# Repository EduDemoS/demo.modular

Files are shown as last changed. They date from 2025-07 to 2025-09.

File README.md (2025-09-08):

# EduDemoS Modular Weather Station

The EduDemoS Modular Weather Station consists of a central Control Box that can be connected to three other demonstrators (solar, wind and water). Due to its modular nature you can even design and connect your own modules or send measurement data wirelessly to the Internet.

This repository contains all necessary files and is structured as follows:

- [doc](doc) contains documentation such as
  - assembly manual
  - bill of material
- [code](code) contains program code to run the model
- [model](model) contains the printable 3D model

# Licensing

Please note: different licenses apply depending on the type of content.

All documents and 3d models (files ending with .pdf and .stl) are licensed under [CC-BY-NC-SA 4.0](https://creativecommons.org/licenses/by-nc-sa/4.0/).

All files containing code are licensed under [GNU GPL V3](https://www.gnu.org/licenses/gpl-3.0.txt).

# Disclaimer:

Funded by the European Union. Views and opinions expressed are however those of the author(s) only and do not necessarily reflect those of the European Union or the European Education and Culture Executive Agency (EACEA). Neither the European Union nor EACEA can be held responsible for them.

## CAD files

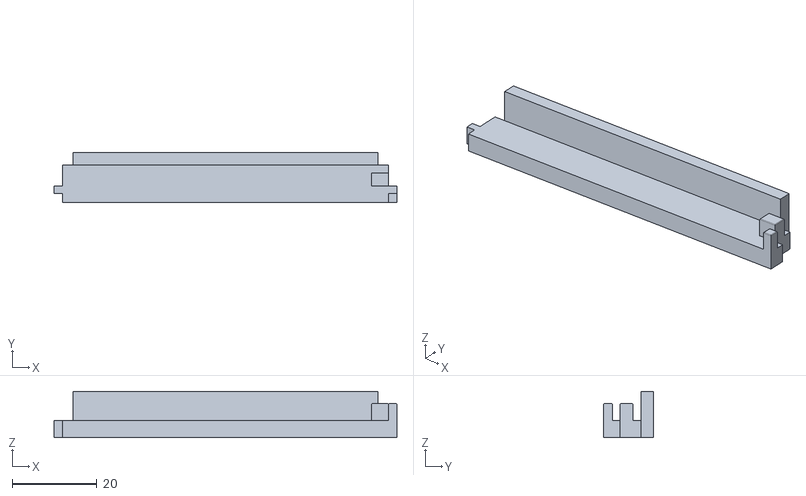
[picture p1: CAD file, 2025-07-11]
model/Controlbox/LCD_Frame_B__Controlbox.stl
80.8 x 11.8 x 10.9

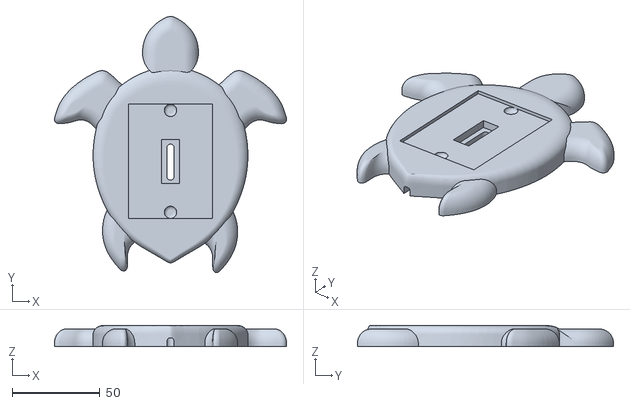
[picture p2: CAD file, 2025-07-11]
model/Sun-Module/Turtle__Sun_Module.stl
132.1 x 145.7 x 12.0

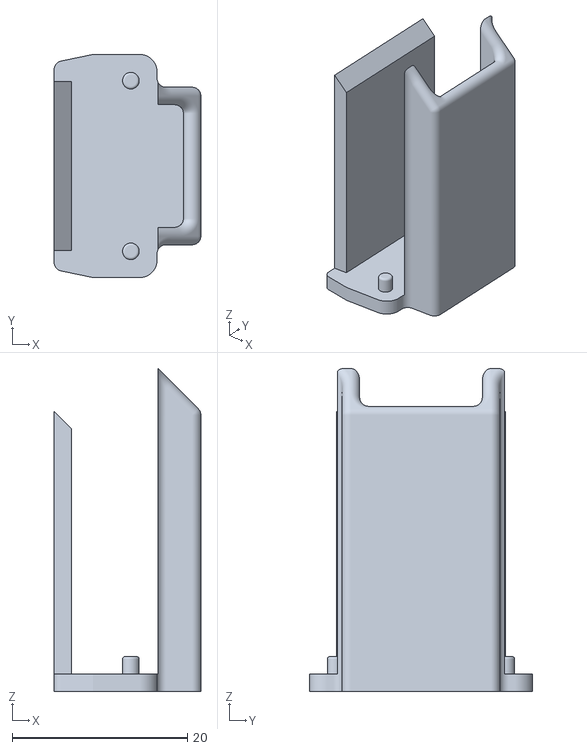
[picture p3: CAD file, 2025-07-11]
model/Water-Module/Electronic_Lid__Water_Module.stl
16.8 x 25.5 x 36.9

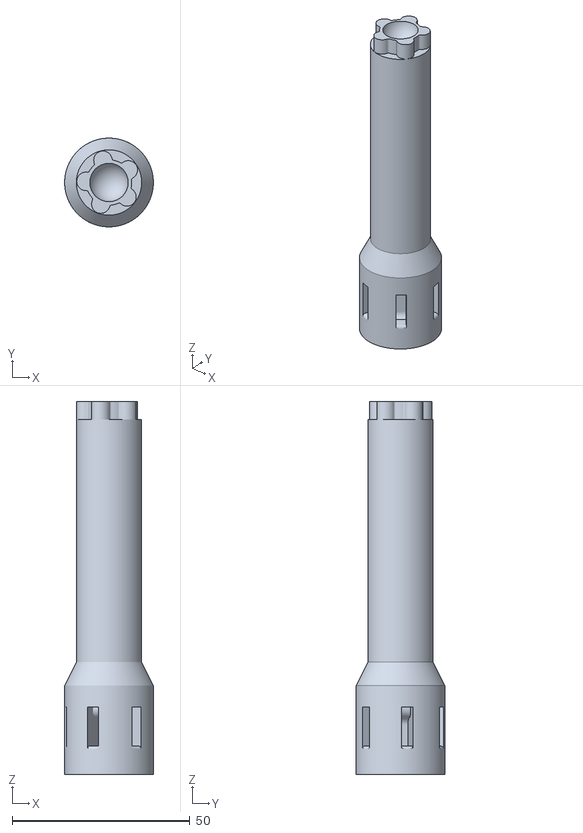
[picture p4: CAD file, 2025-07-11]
model/Wind-Module/Connector__Wind_Module.stl
25.0 x 25.0 x 105.0

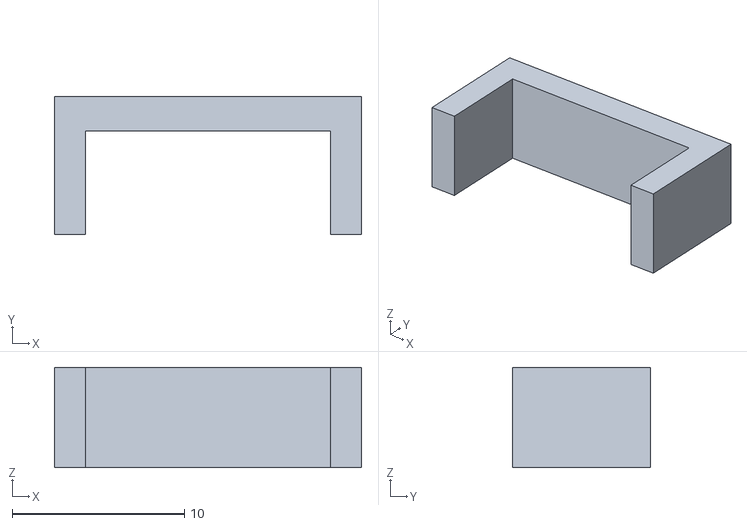
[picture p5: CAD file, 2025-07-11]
model/Controlbox/ACS_Holder__Controlbox.stl
17.8 x 8.00 x 5.80

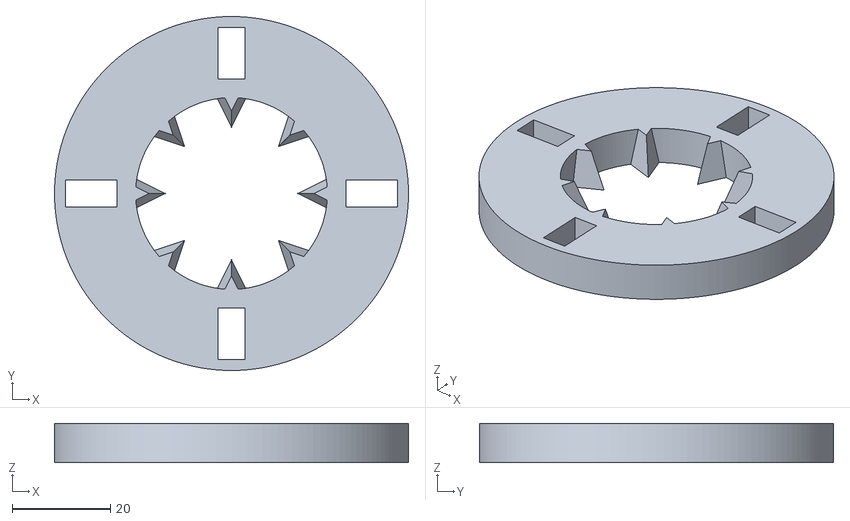
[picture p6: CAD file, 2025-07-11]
model/Water-Module/Lower_Ring__Water_Module.stl
72.0 x 72.0 x 8.00

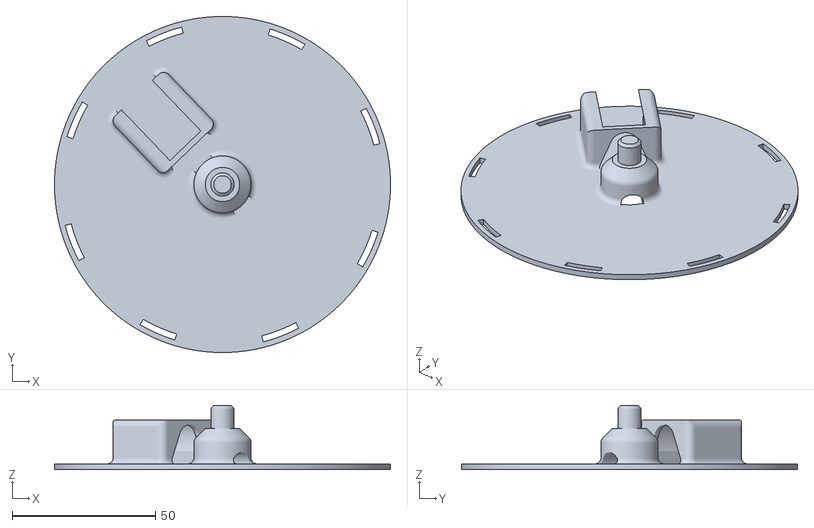
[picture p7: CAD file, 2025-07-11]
model/Wind-Module/Base__Wind_Module.stl
117.5 x 117.5 x 22.4

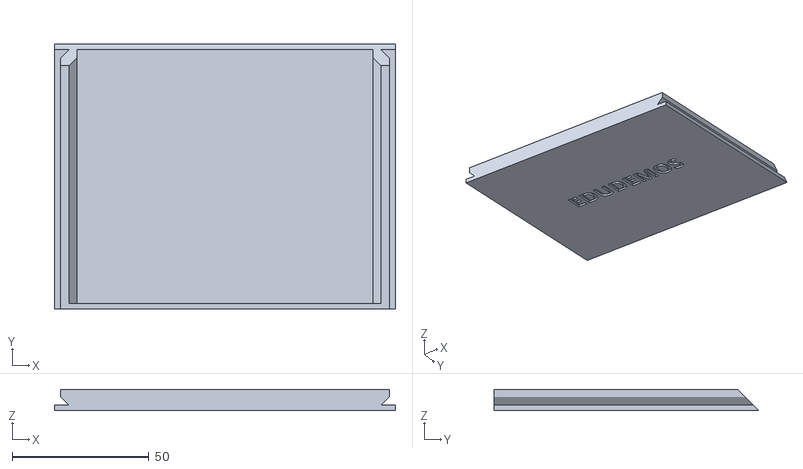
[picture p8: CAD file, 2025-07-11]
model/Controlbox/Lid__Controlbox.stl
124.6 x 96.8 x 7.80

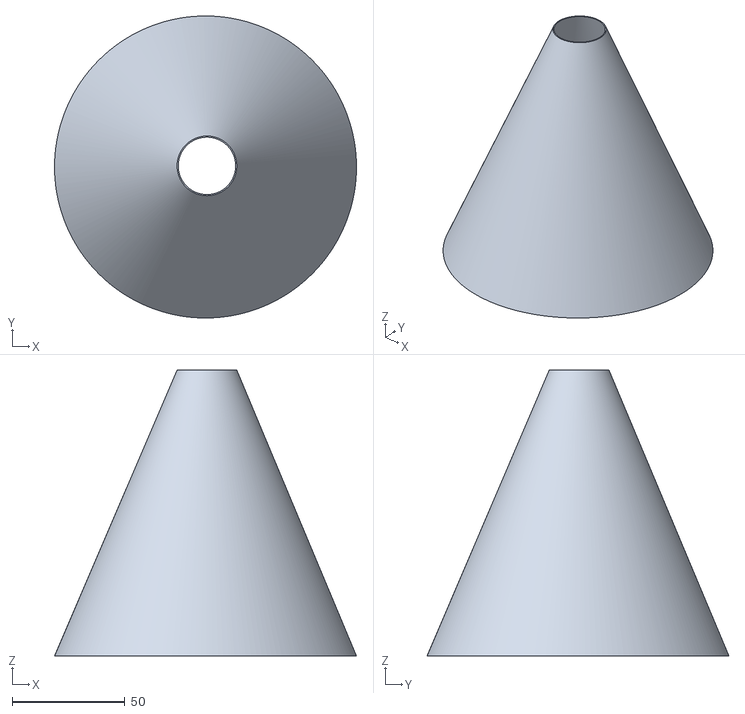
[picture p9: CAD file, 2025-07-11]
model/Water-Module/Collector_Cone__Water_Module.stl
134.1 x 134.1 x 127.0

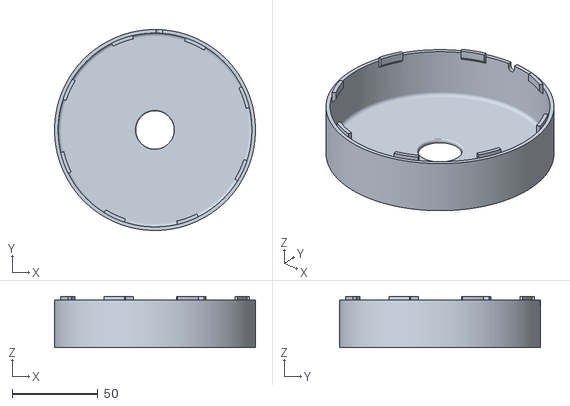
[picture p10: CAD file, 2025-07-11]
model/Wind-Module/Lid__Wind_Module.stl
117.5 x 117.5 x 30.0

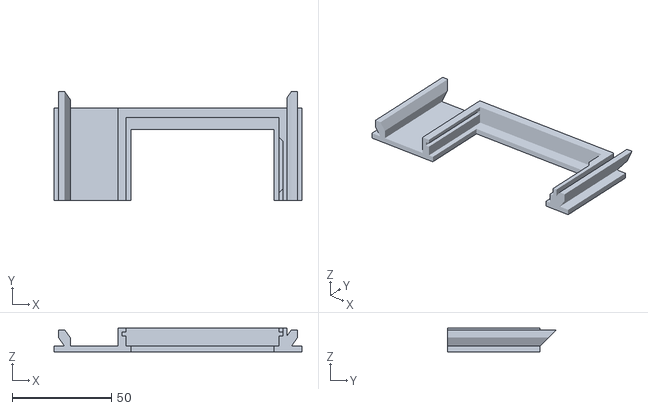
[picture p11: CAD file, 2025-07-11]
model/Controlbox/LCD_Frame_A__Controlbox.stl
124.7 x 54.7 x 11.8

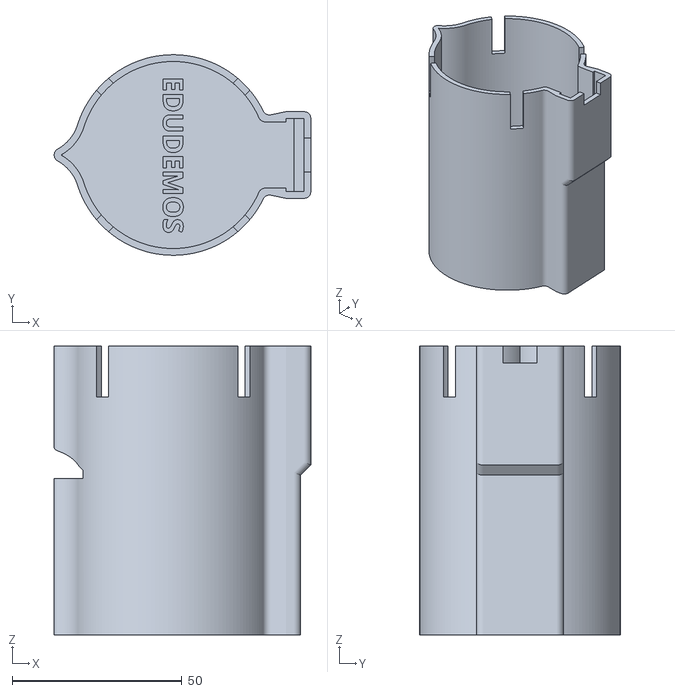
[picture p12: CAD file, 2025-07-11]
model/Water-Module/Cup__Water_Module.stl
75.5 x 59.0 x 85.0

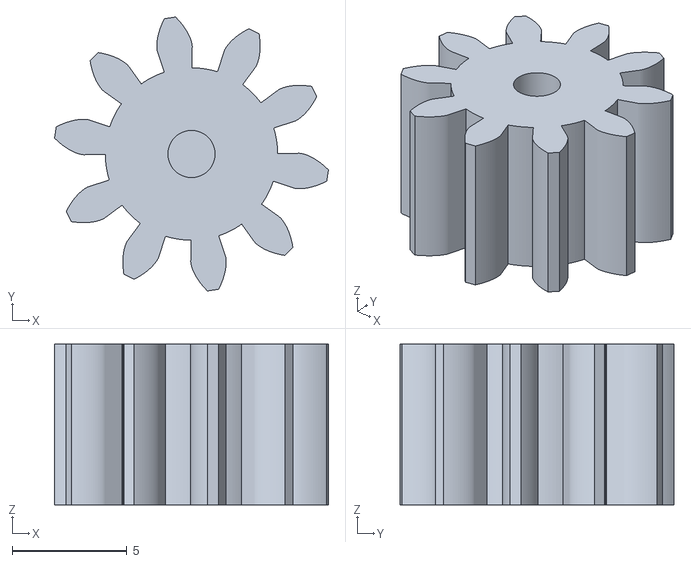
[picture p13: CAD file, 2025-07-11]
model/Wind-Module/Gear_A__Wind_Module.stl
11.9 x 11.9 x 7.00

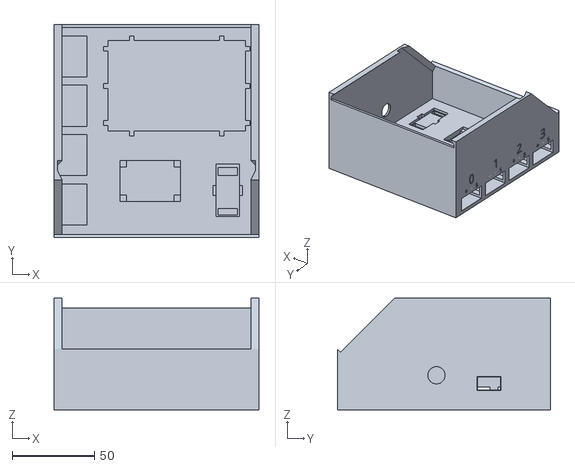
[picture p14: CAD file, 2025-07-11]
model/Controlbox/Base__Controlbox.stl
124.6 x 129.6 x 67.9

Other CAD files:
model/Water-Module/Upper_Ring__Water_Module.stl
model/Water-Module/x4_Cactus__Water_Module.stl

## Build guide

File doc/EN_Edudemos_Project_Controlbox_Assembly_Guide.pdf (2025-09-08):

## EDUcating through Sustainable DEMOnstrators

Funded by the European Union. Views and opinions expressed are however those of the author(s) only and do not necessarily reflect those of the European Union or the European Education and Culture Executive Agency (EACEA). Neither the European Union nor EACEA can be held responsible for them.

## Assembly Guide

# Modular Weather Station

# Controlbox Module

V-09.25

## 1.Materials 2.Step by Step Instructions a.Printing the Parts b.Wiring- and Assemby Instructions 3.Building the Modules 4.Programming 5.Troubleshooting 6.Appendix a.Components with Example Link b.Pinout c.Changing Modules d.Licensing & Disclaimer 7.Contact Information

# Content

# Materials

## Electrical Components

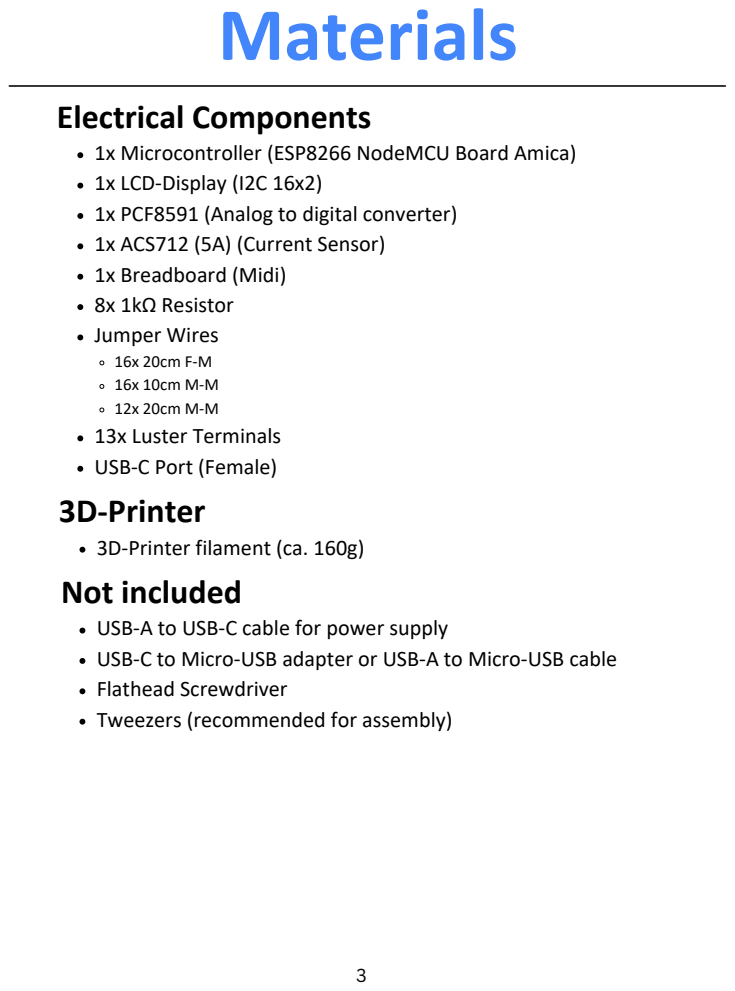
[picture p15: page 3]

1x Microcontroller (ESP8266 NodeMCU Board Amica)
1x LCD-Display (I2C 16x2)
1x PCF8591 (Analog to digital converter)
1x ACS712 (5A) (Current Sensor)
1x Breadboard (Midi)
8x 1kΩ Resistor
Jumper Wires
13x Luster Terminals
USB-C Port (Female)
3D-Printer
3D-Printer filament (ca. 160g)
Not included
USB-A to USB-C cable for power supply
USB-C to Micro-USB adapter or USB-A to Micro-USB cable
Flathead Screwdriver
Tweezers (recommended for assembly)

ESP8266 NodeMCU Board
x1

ACS712
x1

Luster Terminals
x14

x1

x1

Jumper Wire female-to-male (F-M)**
x15

Jumper Wire male-to-male
(M-M)**
x28

USB-C Port Female
x1
Resistor 1kOhm

# Modular Controlbox

### Total 62 elements

## Electronics

*Make sure to remove all jumpers from the PCF8591 **The colours of the jumper wires are irrelevant.

These 6 pins
should not be
connected

# Modular Controlbox

### Total 5 elements

## 3D Printed Parts

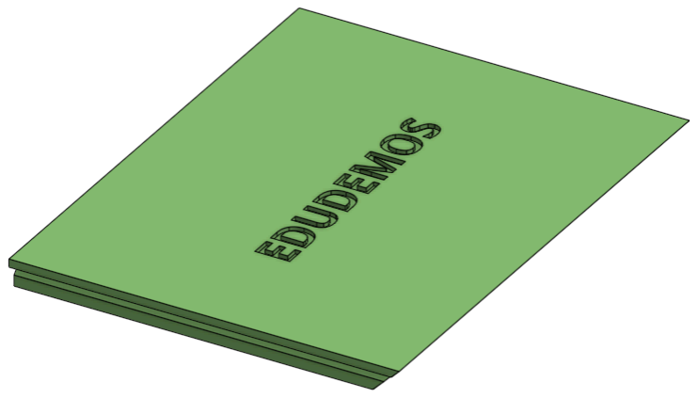
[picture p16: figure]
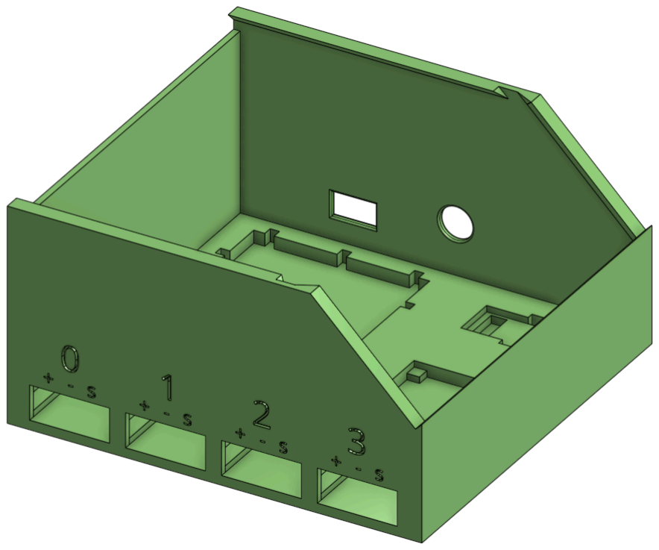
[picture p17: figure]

Controlbox Base
x1

ACS712 Fastener
x1

Controlbox Lid
x1

Display Fastener
x1

Display Holder
x1

This part should be
printed sideways

The STL print files are available on the EduDemoS website:
edudemos.eu/en/demonstrators/

# Step By step Instructions

## a. Print the parts of the Modular Controlbox on any 3D-Printer

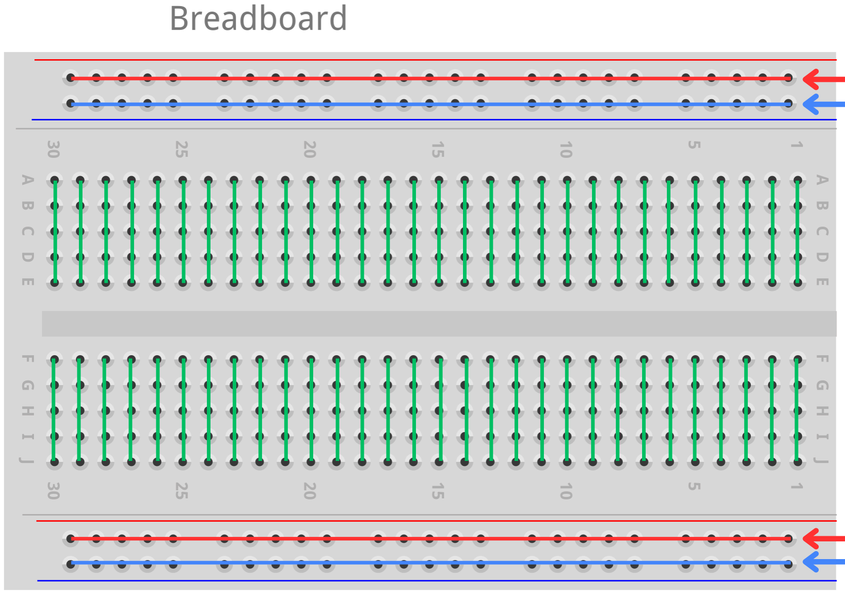
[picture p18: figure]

red-rail

(no internal connection
between the two rails)

blue-rail

## B. Wiring and assembling Instructions

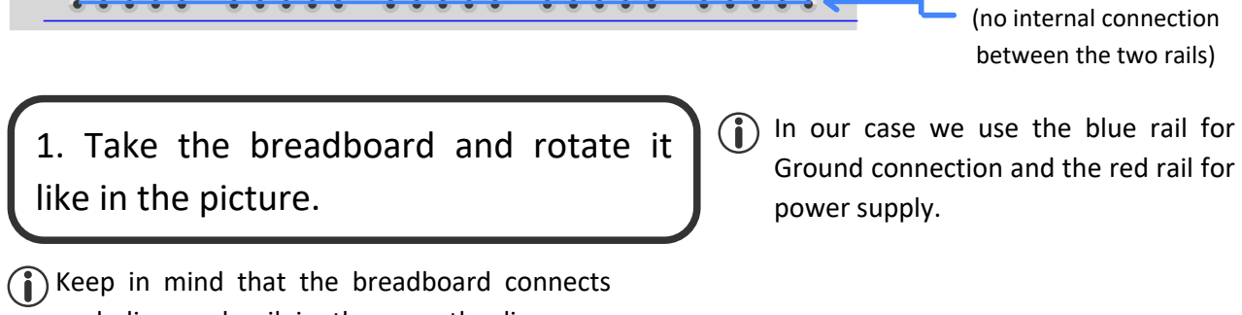
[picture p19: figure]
(no internal connection between the two rails); 1. Take the breadboard and rotate it like in the picture.; In our case we use the blue rail for Ground connection and the red rail for power supply.
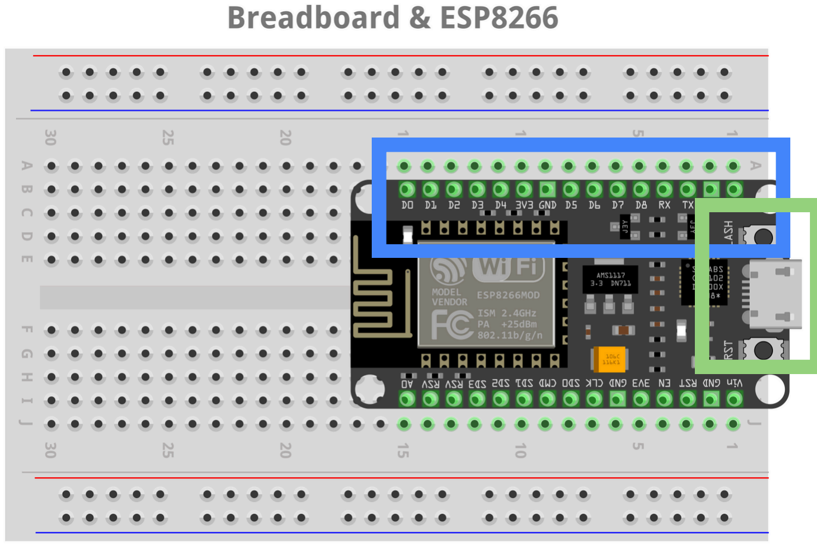
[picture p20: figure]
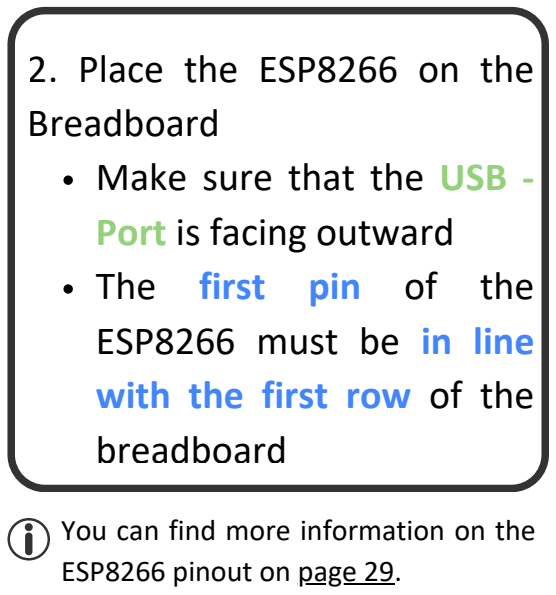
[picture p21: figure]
2. Place the ESP8266 on the Breadboard Make sure that the USB - Port is facing outward The first pin of the ESP8266 must be in line with the first row of the breadboard; You can find more information on the ESP8266 pinout on page 29.

Keep in mind that the breadboard connects each line and rail in the way the lines are drawn. For example a pin or Jumper plugged in to A5 is connected with all Jumper and pins plugged into B5, C5, D5 and E5.

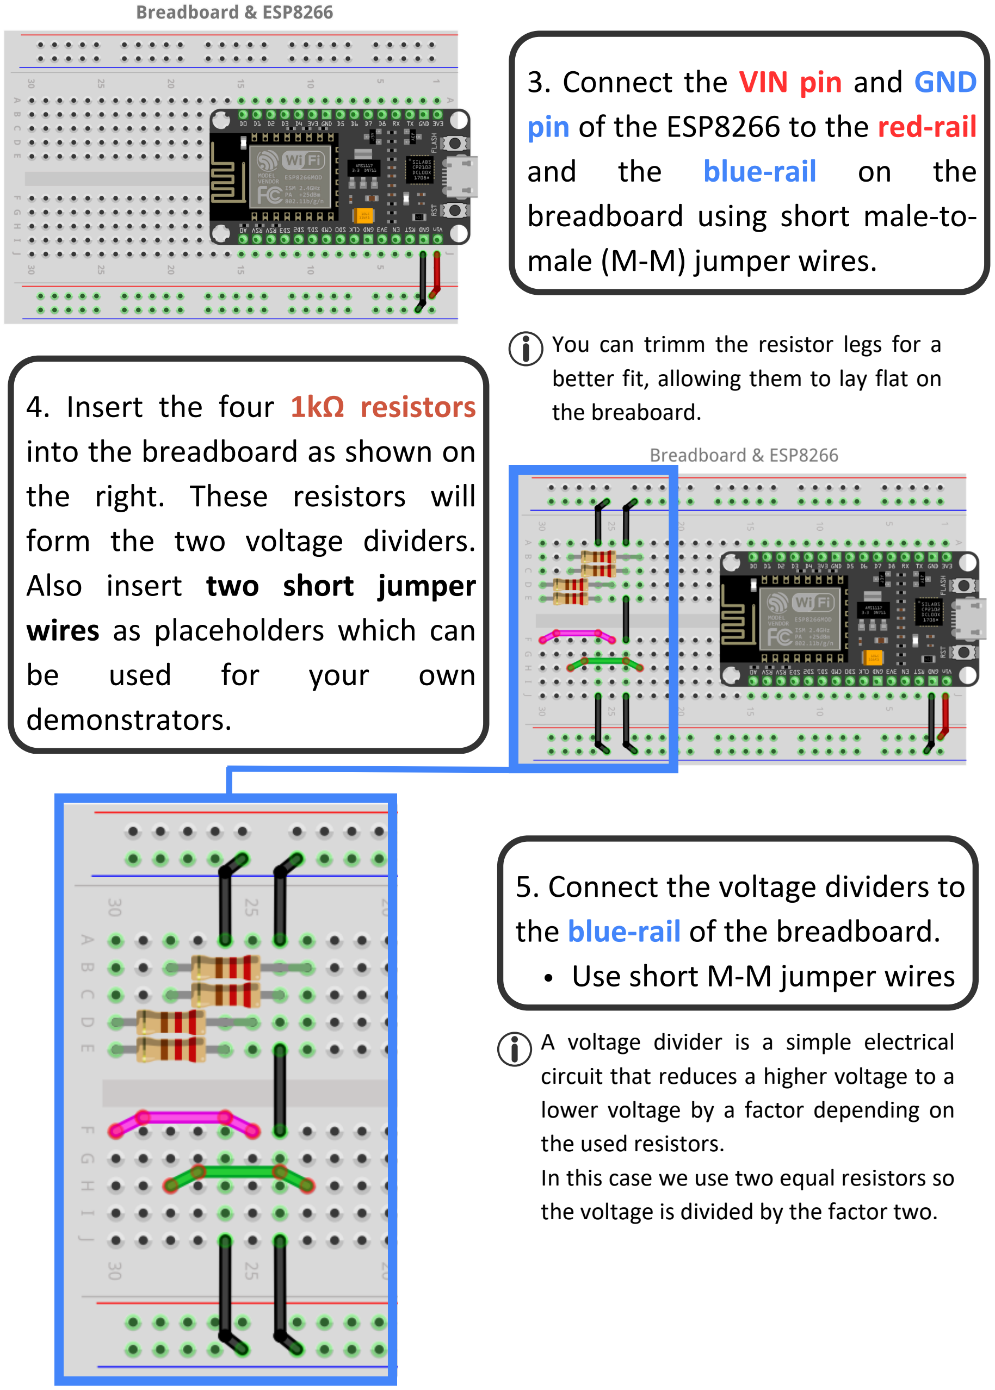
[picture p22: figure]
3. Connect the VIN pin and GND pin of the ESP8266 to the red-rail; and; the; blue-rail; breadboard using short male-to- male (M-M) jumper wires.; 4. Insert the four 1kΩ resistors into the breadboard as shown on the right. These resistors will form the two voltage dividers. Also insert two short jumper wires as placeholders which can; used; for; your; own; demonstrators.; 5. Connect the voltage dividers to the blue-rail of the breadboard. Use short M-M jumper wires; lower voltage by a factor depending on the used resistors.; You can trimm the resistor legs for a; the breaboard.

A voltage divider is a simple electrical circuit that reduces a higher voltage to a

In this case we use two equal resistors so the voltage is divided by the factor two.

better fit, allowing them to lay flat on

I²C is a way for electrical components to communicate. It uses two wires to send and receive digital messages. You can connect multiple components with the same pins because each device has a special adress assigned to it.

6. Connect the D1 and D2 pins from the ESP8266 to rows 18 and 19 on the breadboard.

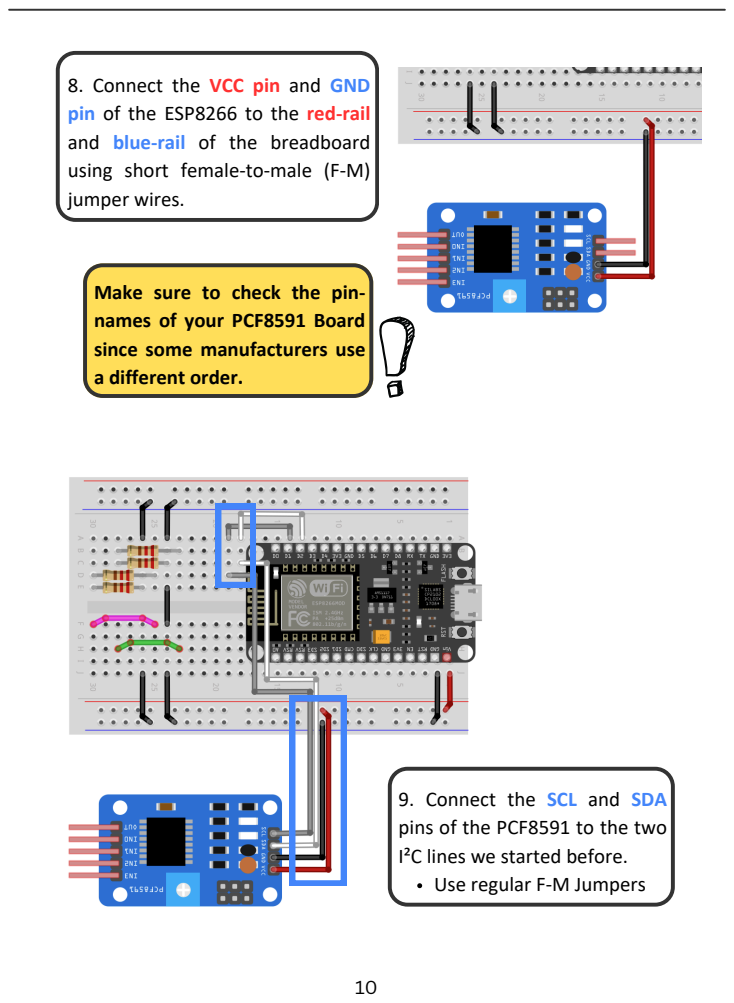
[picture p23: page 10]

8. Connect the VCC pin and GND
pin of the ESP8266 to the red-rail
and blue-rail of the breadboard
using short female-to-male (F-M)
jumper wires.

Make sure to check the pin-
names of your PCF8591 Board
since some manufacturers use
a different order.

9. Connect the SCL and SDA
pins of the PCF8591 to the two
I²C lines we started before.
Use regular F-M Jumpers

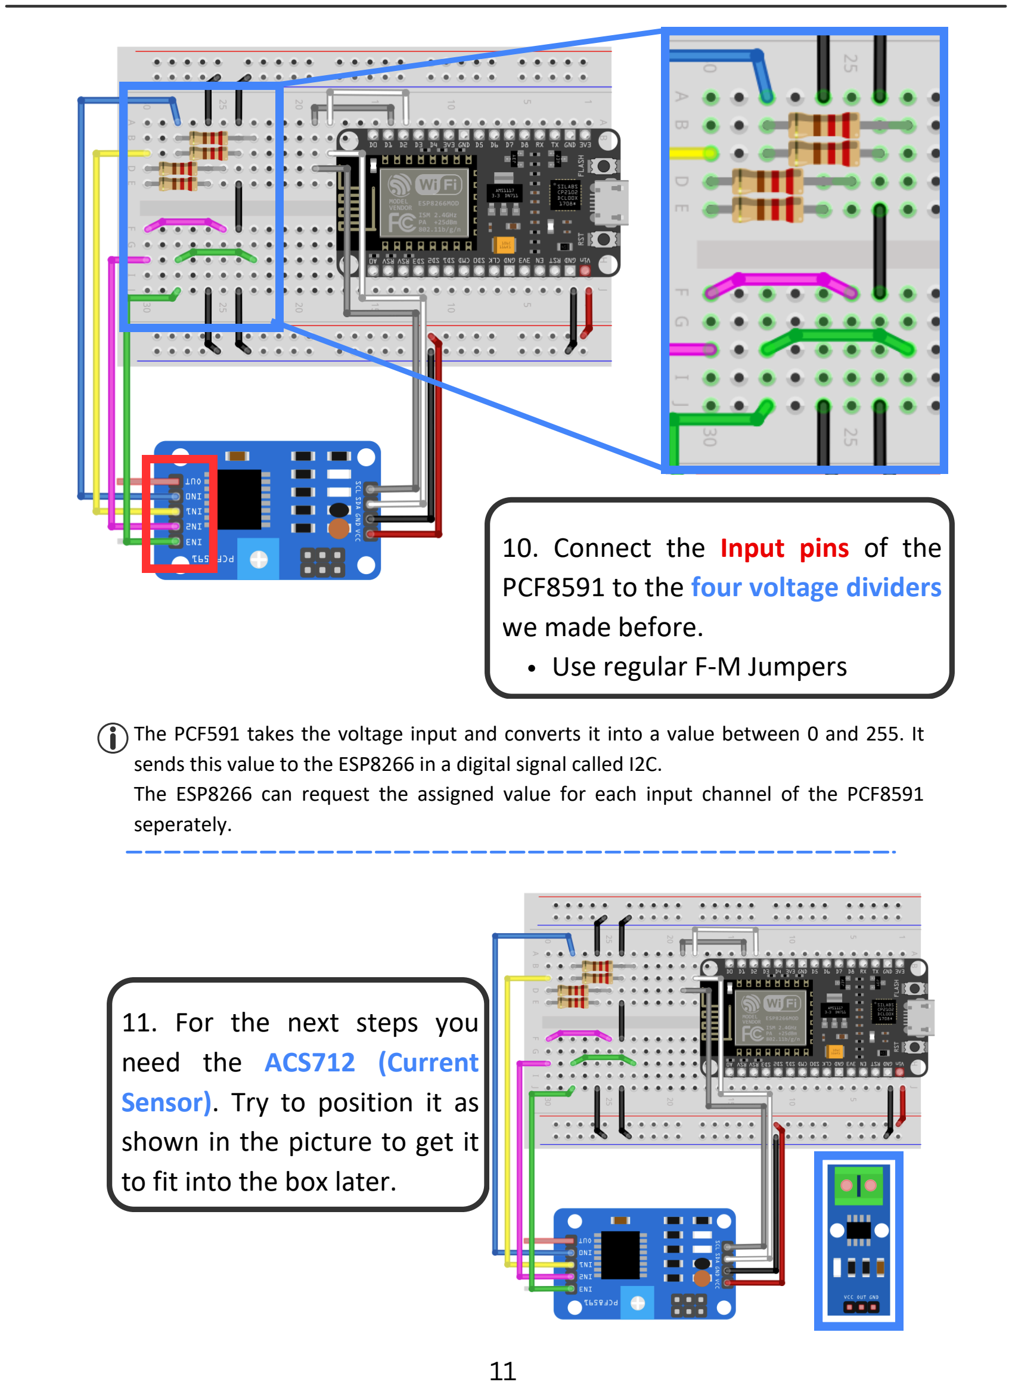
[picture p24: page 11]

11. For the next steps you need the ACS712 (Current
Sensor). Try to position it as shown in the picture to get it to fit into the box later.
10. Connect the Input pins of the PCF8591 to the four voltage dividers we made before.
Use regular F-M Jumpers

The PCF591 takes the voltage input and converts it into a value between 0 and 255. It sends this value to the ESP8266 in a digital signal called I2C.
The ESP8266 can request the assigned value for each input channel of the PCF8591 seperately.

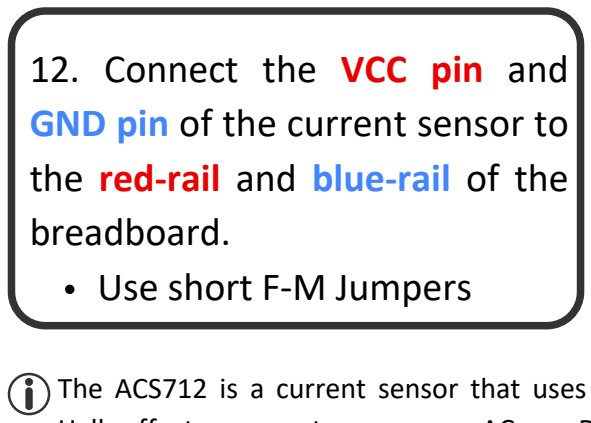
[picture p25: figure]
12. Connect the VCC pin and GND pin of the current sensor to the red-rail and blue-rail of the breadboard. Use short F-M Jumpers

The ACS712 is a current sensor that uses a Hall effect sensor to measure AC or DC current and outputs an analog voltage proportional to the current flow.

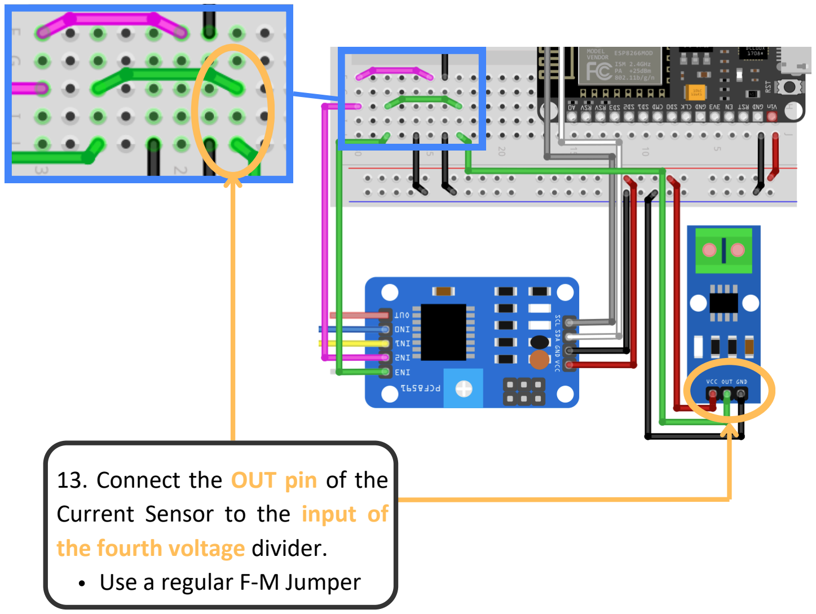
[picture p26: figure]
13. Connect the OUT pin of the Current Sensor to the input of the fourth voltage divider. Use a regular F-M Jumper

15. Get a single Luster
Terminal | so | you | can
connect | the | | USB-C
connector later.
14. Partially unscrew the left terminal connector of the Current Sensor, put one side of the jumper in the opening and screw it tight again. Connect the other end of the jumper wire to the red-rail of the breadboard.
Use a short M-M Jumper

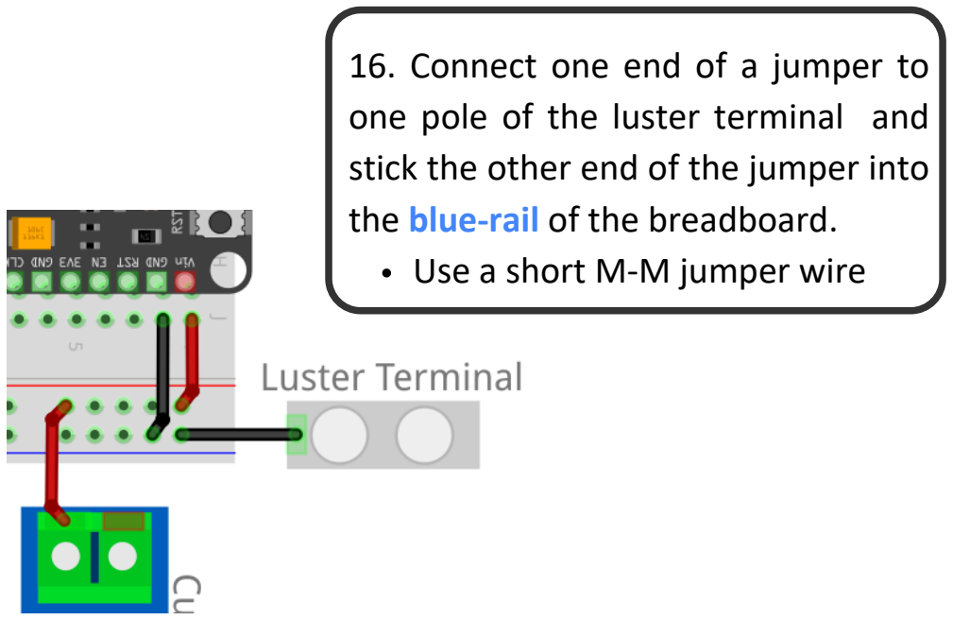
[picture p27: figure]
16. Connect one end of a jumper to one pole of the luster terminal and stick the other end of the jumper into the blue-rail of the breadboard. Use a short M-M jumper wire

17. For the next steps, you will need four luster terminals, each with 3 poles. These terminals will connect the control box to various modules. Position them as shown in the picture to ensure everything fits into the box later.

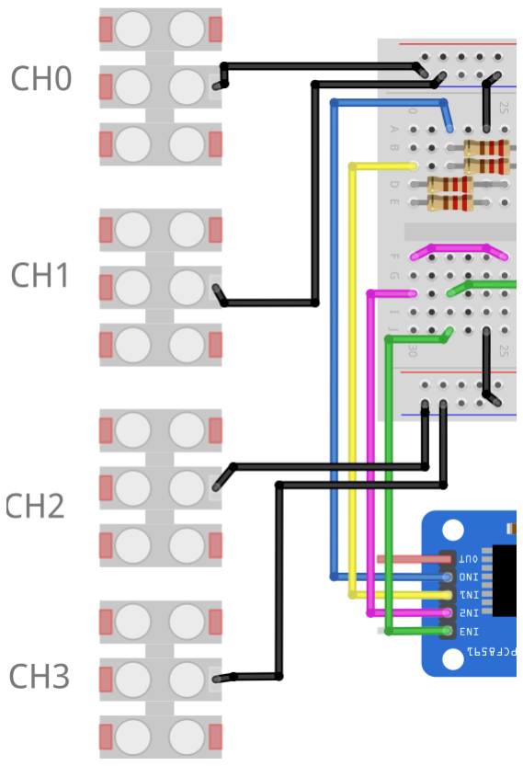
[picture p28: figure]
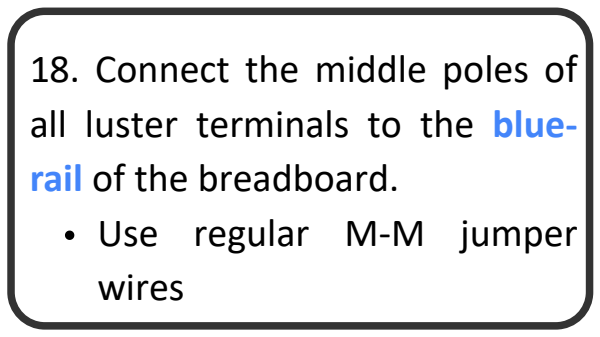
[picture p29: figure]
18. Connect the middle poles of all luster terminals to the blue- rail of the breadboard. Use regular M-M jumper wires

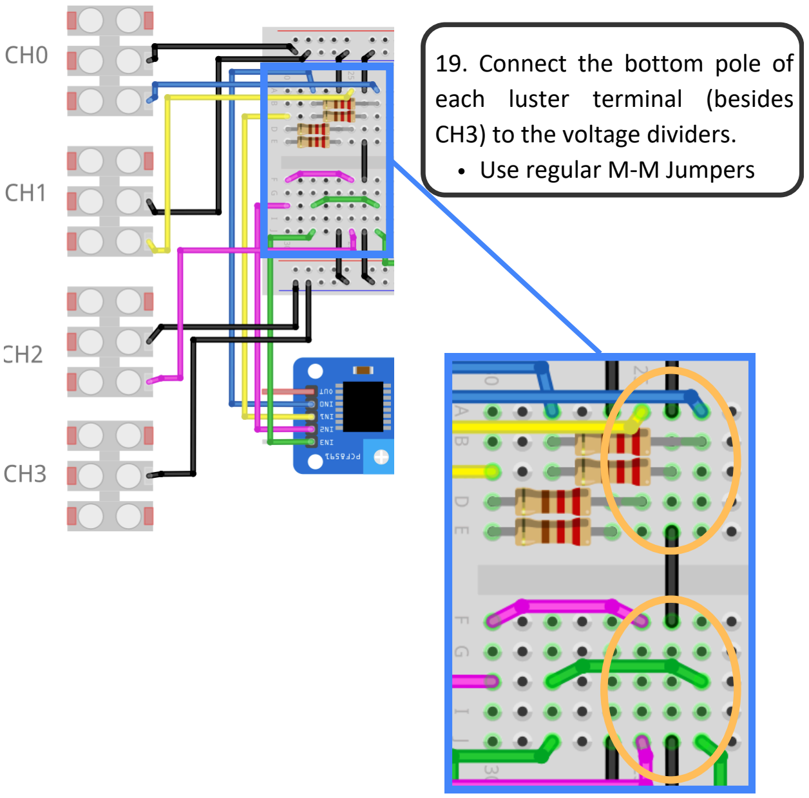
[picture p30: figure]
19. Connect the bottom pole of each luster terminal (besides CH3) to the voltage dividers. Use regular M-M Jumpers
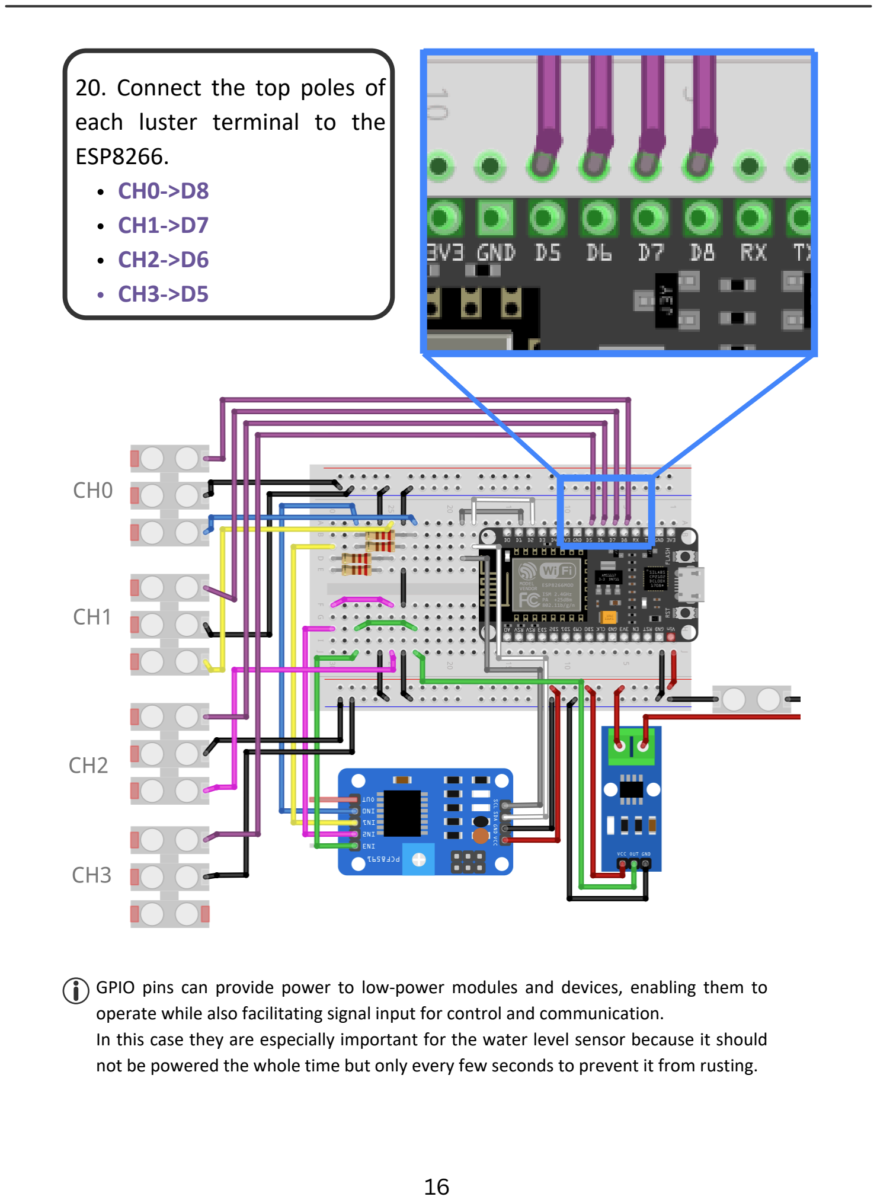
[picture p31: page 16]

20. Connect the top poles of each luster terminal to the ESP8266.
CH0->D8
CH1->D7
CH2->D6
CH3->D5

GPIO pins can provide power to low-power modules and devices, enabling them to operate while also facilitating signal input for control and communication.
In this case they are especially important for the water level sensor because it should not be powered the whole time but only every few seconds to prevent it from rusting.

21. Put everything in the 3D-printed Controlbox base, the parts should fit in the holes.
It might be helpful to glue the luster terminals in place. If you decide to do so, keep in mind that you have to reach all screws with a screwdriver to connect the modules later.
22. Fasten the Current Sensor with the small bridge to keep it in place.

It is important to keep the Current Sensor in place because of the way it measures the current. If the sensor is near other wires, the current in the wires could interfere with the magnetic field of the current that is measured.

24. After placing the USB-C Port in the wall of the Controlbox, you can now connect the cable to the luster terminal, which is connected to the breadboard and Current Sensor. Make sure to connect the black wire from the USB-C connector to the terminal which is connected with the blue-rail and the red wire from the USB-C connector goes into the ACS current sensor.
25. For the next steps we
need the LCD Display. Try
to position it in the same direction as shown in the
picture to get it to fit into the box later.
Do not put the LCD
display in the box yet.
23. Put the USB-C Port through the hole in the right wall of the controlbox.

An LCD display, or Liquid Crystal Display can control which colors you see by adjusting the crystals in different ways. The model we use only shows one color.

26. Connect the GND
and VCC pins of the
LCD Display to the
blue-rail and red-rail
of the breadboard.
Use regular F-M
Jumpers
27. Connect the SDA and
SCL pin of the LCD Display to the two I2C lines we
started before.
Use regular F-M
Jumpers

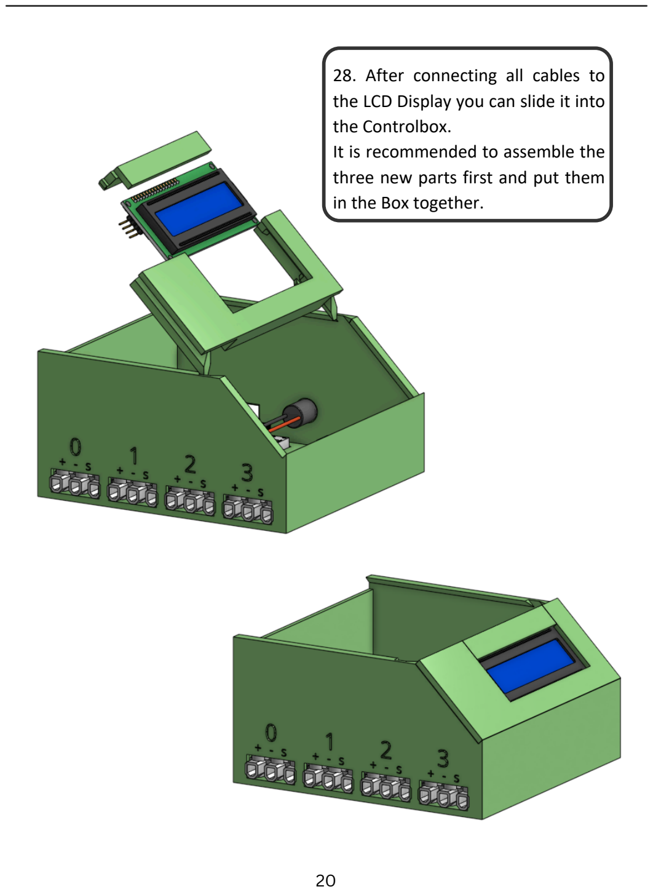
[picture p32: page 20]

28. After connecting all cables to the LCD Display you can slide it into the Controlbox.
It is recommended to assemble the three new parts first and put them in the Box together.

29. Before closing the control box you need to build and connect the modules.
The individual guides can be found on the website https://edudemos.eu/en/demonstrators/. The instuctions also explain how to connect the modules to the Control Box. Below you can see the modules we have created for you.

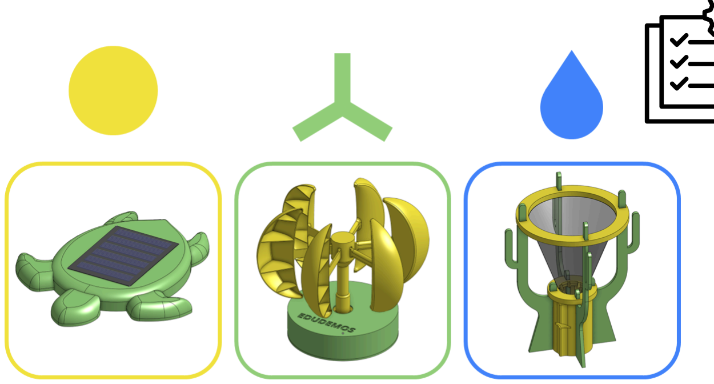
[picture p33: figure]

Once you have finished one or all the modules you can come back to this guide and see how to install and programm this demonstrator using the Arduino IDE.

# Installation Guide

The Arduino IDE (Integrated Development Enviroment) is the software used to write, compile and upload code to your board. (In this case the ESP8266.)

## What is the Arduino IDE?

Step 1: Go to the Arduino Website
Open your web broswer and visit the official Arduino website: https://www.arduino.cc/

## Downloading and installing the Arduino IDE:

Step 2: Navigate to the Download Page
From the homepage, click on “Software” in the top menu, then select “Downloads“
Step 3: Choose Your Operating System
On the Downloads page, select the appropriate version of the Arduino IDE for your operating system (Windows, macOS, or Linux).
Step 4: Download the Installer
Click on the download link, and if prompted, you can choose to contribute or simply download without contributing.
Step 5: Install the Arduino IDE
For Windows:
Run the downloaded .exe file.
Follow the installation wizard to install the IDE.
Check the option to install the USB driver when prompted. For macOS:
Open the downloaded .dmg file.
Drag the Arduino IDE to the Applications folder.

## Cofiguring the Arduino IDE:

Step 1: Add the ESP8266 Board URL
To use the ESP8266 with the Arduino IDE, you need to include the appropriate URL in the IDE's preferences:
1.Open the Arduino IDE.
2.Go to File > Preferences (on macOS, this might be under Arduino > Preferences).
3.In the Additional Board Manager URLs field, paste the following URL:
http://arduino.esp8266.com/stable/package_esp8266com_index.jso n
4.If there are already other URLs listed, separate them with a comma.

For Linux:
Extract the downloaded .tar.xz file. Run the install.sh script in the terminal.
Step 6: Verify Installation
Open the Arduino IDE to ensure it launches correctly.

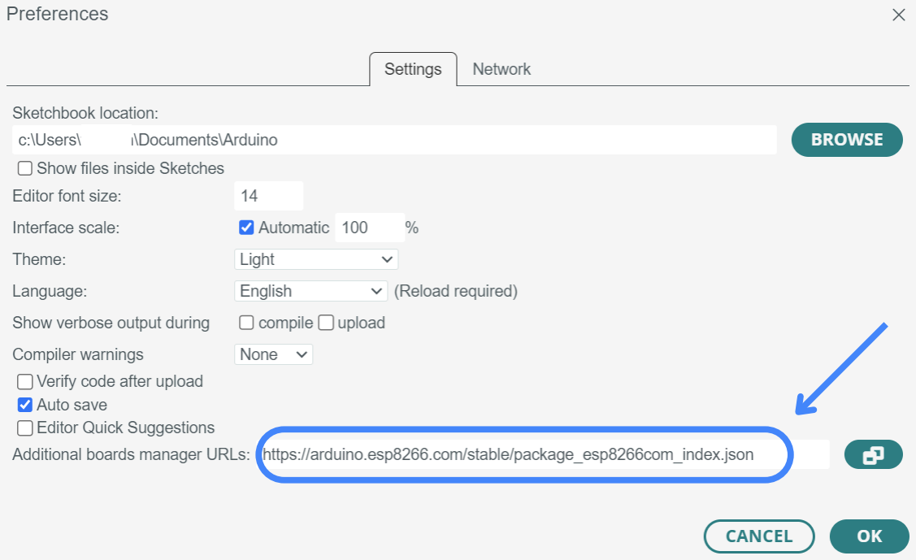
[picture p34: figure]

Step 2: Install the ESP8266 Board Package
1.Go to Tools > Board > Boards Manager.
2.In the search bar, type ESP8266.
3.Select esp8266 by ESP8266 Community and click Install. 4.Wait for the installation to complete.

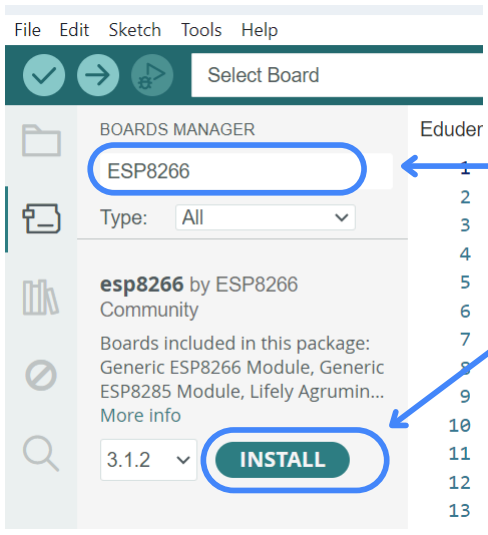
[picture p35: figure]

Step 3: Select the ESP8266 Board
1.Connect your ESP8266 board to your computer using a USB cable. 2.Go to Tools > Board and select Generic ESP8266 Module.
3.Go to Tools > Port and select the correct COM port for your board.

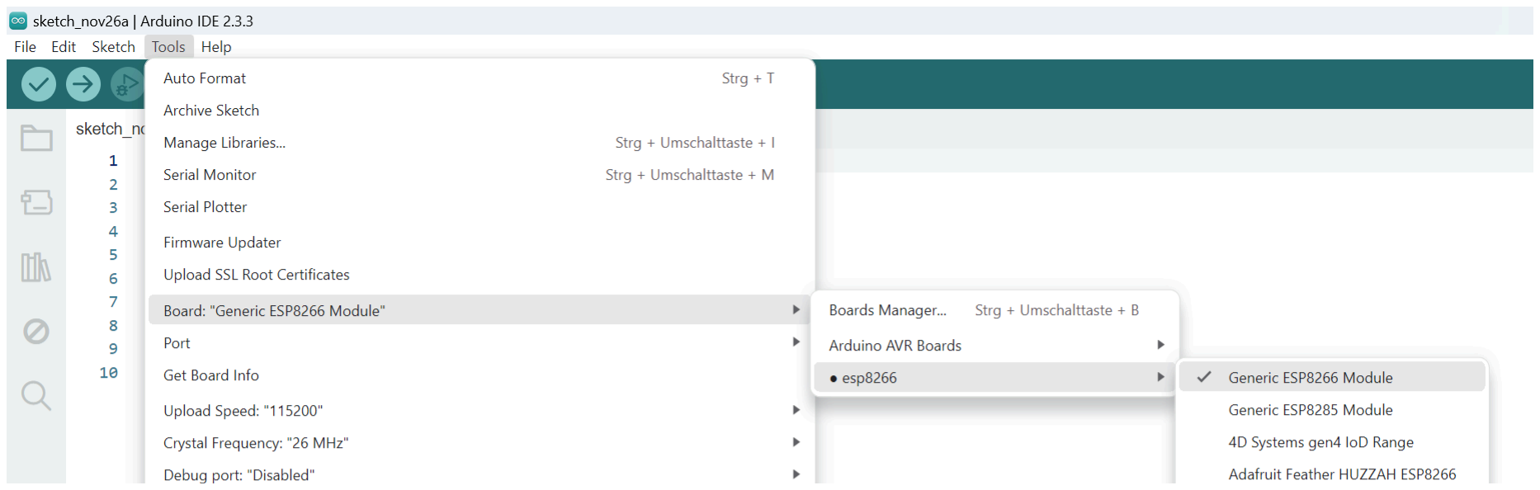
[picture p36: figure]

Step 4: Test the Setup
1.Open the Examples menu in the Arduino IDE:
2.File > Examples > ESP8266 > Blink.
3.Verify and upload the sketch to your ESP8266.
4.The onboard LED on the ESP8266 should blink if everything is set up correctly.
Upload Button

# Code

## Download the Missing Library to Run the Code

Step 3: Move the Library to the Correct Folder:
Navigate to the folder where your Arduino sketches are stored (e.g.,
Documents/Arduino/libraries | on | Windows | or
~/Documents/Arduino/libraries on macOS/Linux).
Create a new folder in the libraries directory with the same name as the library (e.g., LiquidCrystal_I2C).
Move the contents of the extracted archive into that folder. The files inside should have a path like “Documents/Arduino/libraries/LiquidCrystal_I2C.h”
Step 1: Download the Library:
Go to the EduDemoS website https://edudemos.eu/en/demonstrators/ (https://edudemos.eu/en/demostrators/) and click on the Programming button. Dowload the ZIP folder called “libraries.zip”
Step 2: Extract the ZIP File
Extract the downloaded ZIP file on your computer using a ZIP extractor such as WinRAR, 7-Zip, or the default extractor of your operating system.

Once the library is in the correct folder, it will be available for use in your Arduino IDE.

Open the Arduino IDE and load the code into a new sketch. Finally you can upload the code to your ESP8266.
You should now see on the LCD Display how much current voltage is being generated by the solar panel.

## Running the Code

The code for the Turtle is available on the EduDemoS website under the Programming button.
https://edudemos.eu/en/demonstrators/ (https://edudemos.eu/en/demostrators/)

## Where to Find the Code

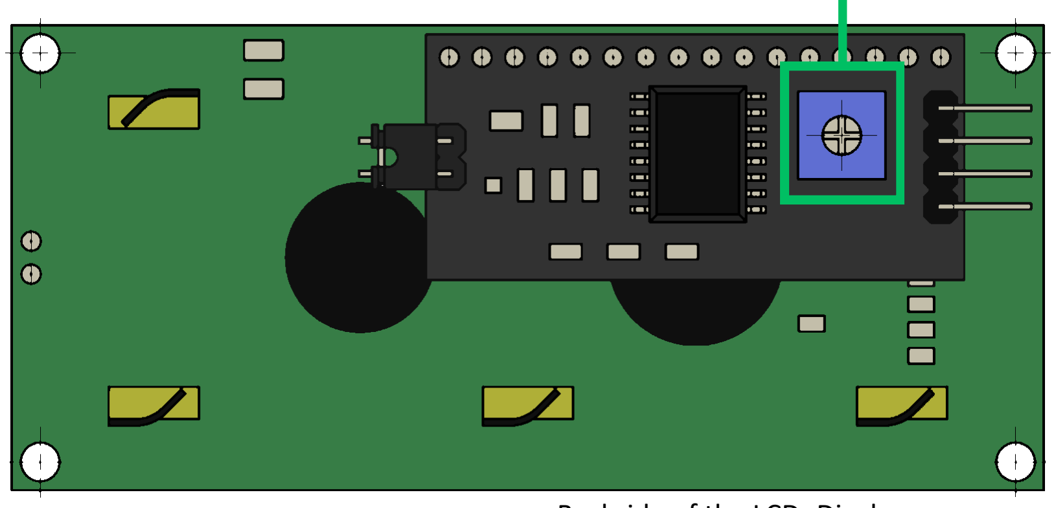
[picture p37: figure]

31. If you want to, you can remove the USB Cable connected to the ESP8266. The Controlbox just needs the USB-C cable plugged in to work.
30. If the display is unreadable because it is too bright or too dark, flip the display to its back and turn the screw in the potentiometer until the symbols on the display become readable. Potentiometer

Backside of the LCD- Display

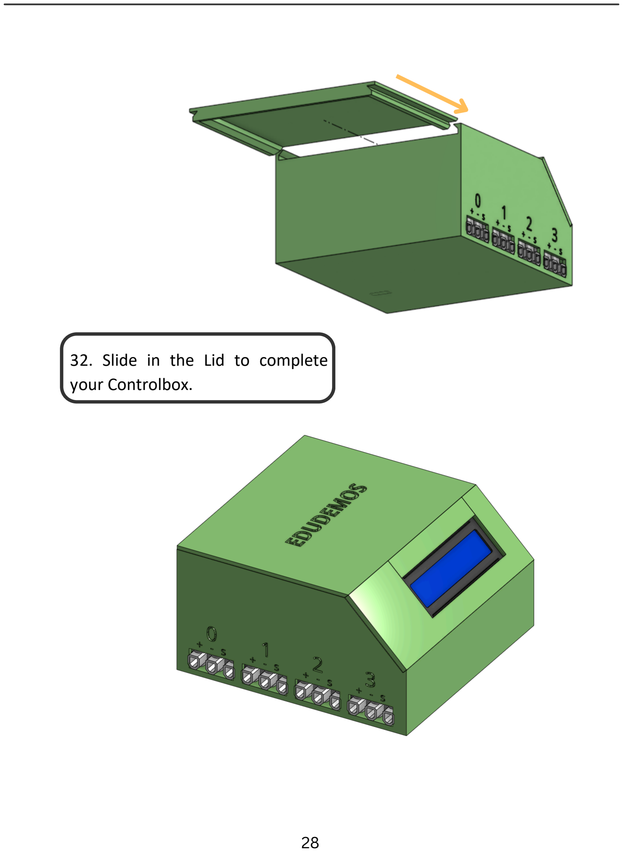
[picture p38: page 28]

32. Slide in the Lid to complete your Controlbox.

What else can you imagine?

Personalize your own demonstrator, and share your ideas and feedback with us at
edudemos@technikmachtspass.org
33. The finished control box with all its modules should look somewhat like this when finished.

# Troubleshooting

## General Issues

Restart the Arduino IDE if changes don’t take effect.
Open the Serial Monitor (Tools > Serial Monitor) to check for error messages.
Double-check your wiring, especially the I2C connections and power. If nothing works, try disconnecting and reconnecting the ESP8266, then press the RST (Reset) button to restart the board.

## Installation Issues

Arduino IDE Won't Install:
Ensure your computer meets the minimum requirements for the Arduino IDE.
Download the correct version for your operating system from https://www.arduino.cc/en/software.
On Windows, run the installer as an administrator.

## Code Upload Errors

Use a good-quality USB cable (some cables are for power only, not data).
Common Upload Error Messages:
Failed to connect to ESP8266:
Hold the BOOT/FLASH button on the ESP8266 while uploading the code.
After the upload is complete, press the RST (Reset) button to reboot the board and run the code.
Serial port not found:
Check the USB connection and ensure the right port is selected in Tools > Port.
It could also be a Driver Issue (read next section).

## USB Driver Issues

If your ESP8266 or its port is not recognized by your computer, you may need to install the appropriate USB-to-Serial driver. ESP8266 boards use the CP210x chip:
Download the Driver
Go to the official Silicon Labs website: https://www.silabs.com/developer-tools/usb-to-uart-bridgevcp-drivers?tab=downloads (https://www.silabs.com/developer-tools/usb-to-uart-bridge-vcp-drivers?tab=downloads)
Download the appropriate version for your operating system (Windows Universal Driver for Windows 10 an 11)
Still Not Detected?
Try a different USB cable (some cables are power-only and don’t support data).
Ensure no other devices are interfering with the USB ports.
Restart your computer after installing the driver.

## I2C Display Not Working

No Display Output:
Verify SDA and SCL pins are correctly connected:
Default ESP8266 pins: SDA = GPIO4 (D2), SCL = GPIO5 (D1). Ensure the I2C address in the code matches the display's address. Use an I2C scanner sketch to confirm the address.
If you can’t see anything or you have trouble reading the Display, make sure that you put everything properly together. If everything is correctly assembled, try adjusting the potentiometer on the back of the Display.
Display Flickers or Shows Garbage Data:
Use pull-up resistors (4.7kΩ) on SDA and SCL lines if not already present.
Ensure the power supply is stable (ESP8266 and display both get sufficient power).

# Appendix

Quantity | Name | Specification | Size | Example Link | Last Update
1 | ESP8266 | NodeMCU Board Amica V2 | 48x26x 13mm | https://amzn.eu/d/gnZ5Kst | 28.11.2024
1 | LCD Display | I2C 16x2 (pre-soldered) | | https://amzn.eu/d/0KgODaI | 28.11.2024
1 | PCF8591 | AD/DA Konverter, I2C, 8Bit | | https://www.roboter-bausatz.de/p/pcf8591-ad-da-konverter-analog-zu-digital-wandler (https://www.roboter-bausatz.de/p/pcf8591-ad-da-konverter-analog-zu-digital-wandler) | 28.11.2024
1 | ACS712 | 5A | | https://www.reichelt.de/de/de/entwic klerboards-stromsensor-bis-5-a-acs712elc-05b-debo2-sen-strom-p282585.html?nbc=1&&r=1 (https://www.reichelt.de/de/de/entwicklerboards-stromsensor-bis-5-a-acs712elc-05b-debo2-sen-strom-p282585.html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) | 28.11.2024
1 | Bread-board | Mini | 400 Pin | https://amzn.eu/d/gEZwM3o | 28.11.2024
16 | Jumper Wire | F-M | 20cm | https://amzn.eu/d/cPTe2WY | 28.11.2024
12 | Jumper Wire | M-M | 20cm | https://amzn.eu/d/0WQP3MI | 28.11.2024
16 | Jumper Wire | M-M | 10cm | https://amzn.eu/d/fAQLBr9 | 29.11.2024
13 | Luster Terminal | | | https://amzn.eu/d/jf2sQKD (https://amzn.eu/d/f4dj6x6) | 28.11.2024
1 | USB-C Port | Female, 5V | | https://amzn.eu/d/bjhGCws | 28.11.2024
4 | Resistor | 1kOhm | | https://amzn.eu/d/39sEK1f | 29.11.2024

## Components with Example Link: Control Box

## Components with Example Link: Sun Module

Quantity | Name | Specification | Size | Example Link | Last Update
1 | Bearing | 608zz | 8x22x7 mm | https://amzn.eu/d/2ETHdLh | 29.11.2024
1 | DC Motor | 1.5V - 6V | | https://amzn.eu/d/8LkNNqp | 29.11.2024
2 | Wire | At least one male end | >20cm | https://amzn.eu/d/3GGCBPu | 29.11.2024

## Components with Example Link: Water Module

Quantity | Name | Specification | Size | Example Link | Last Update
1 | Water Level Sensor | 5V | 50x16 mm | https://amzn.eu/d/1Ewnpv9 | 29.11.2024
3 | Jumper Wire | | 40cm | https://amzn.eu/d/3GGCBPu | 29.11.2024

## Components with Example Link: Sun Module

Quantity | Name | Specification | Size | Example Link | Last Update
1 | Solar Panel | 3V, 0.3W | 65x48 mm | https://amzn.eu/d/hDaVRu9 | 29.11.2024

Nodemcu ESP8266 Pinout, Features, and specifications (electroniclinic.com) (https://www.electroniclinic.com/nodemcu-esp8266-pinout-features-and-specifications/)

## Pinout ESP8266

Because of the modular design, you can change the modules or connect your own.
Wiring Changes
Keep in mind, that the PCF8591 has a range from 0-5V, so everything above that voltage will damage the board.
To achieve a broader possible voltage range, you can use a voltage divider, similar to how it is done for channels 0 and 1. For doubling the range you need two of the same resistors, we suggest 1kOhm.
If you stay within the 0-5V range you can connect the two lines with a jumper, as used in channel 2 and 3.
If you want to change anything on channel 3 you have to disconnect the ACS712 and connect its S luster terminal to J23.

## Changing Modules

Code Changes

To implement the changes in the code you will need to adjust the Channel settings in the lines 63 to 86 of the code.
If you just swapped modules you can copy all the standard settings from one Channel to another (except the GPIO_POWER_PIN).
If you use your own module you might need to calculate your own Slope and Offset. It might be helpful to adjust the update rate as well (standard is 2).
The formula used to calculate the output value is [output value]= [input voltage]*[slope]+[offset].

EduDemoS Modular Weather Station © 2025 by Gerda Stetter Stiftung – Technik macht Spaß! is licensed under Creative Commons Attribution-NonCommercial-ShareAlike 4.0 International. To view a copy of this license, visit https://creativecommons.org/licenses/by-nc-sa/4.0/

All Circuits were created with Fritzing. (https://fritzing.org/)
Some images are based on modules from GrabCAD Library. (https://grabcad.com/library)

## Licensing

## Disclaimer

Funded by the European Union. Views and opinions expressed are however those of the author(s) only and do not necessarily reflect those of the European Union or the European Education and Culture Executive Agency (EACEA). Neither the European Union nor EACEA can be held responsible for them.

# Appendix

# Get In Touch With Us

## edudemos@technikmachtspass.org

## EDUcating through Sustainable DEMOnstrators

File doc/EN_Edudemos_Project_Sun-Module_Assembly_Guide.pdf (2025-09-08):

## EDUcating through Sustainable DEMOnstrators

## Assembly Guide

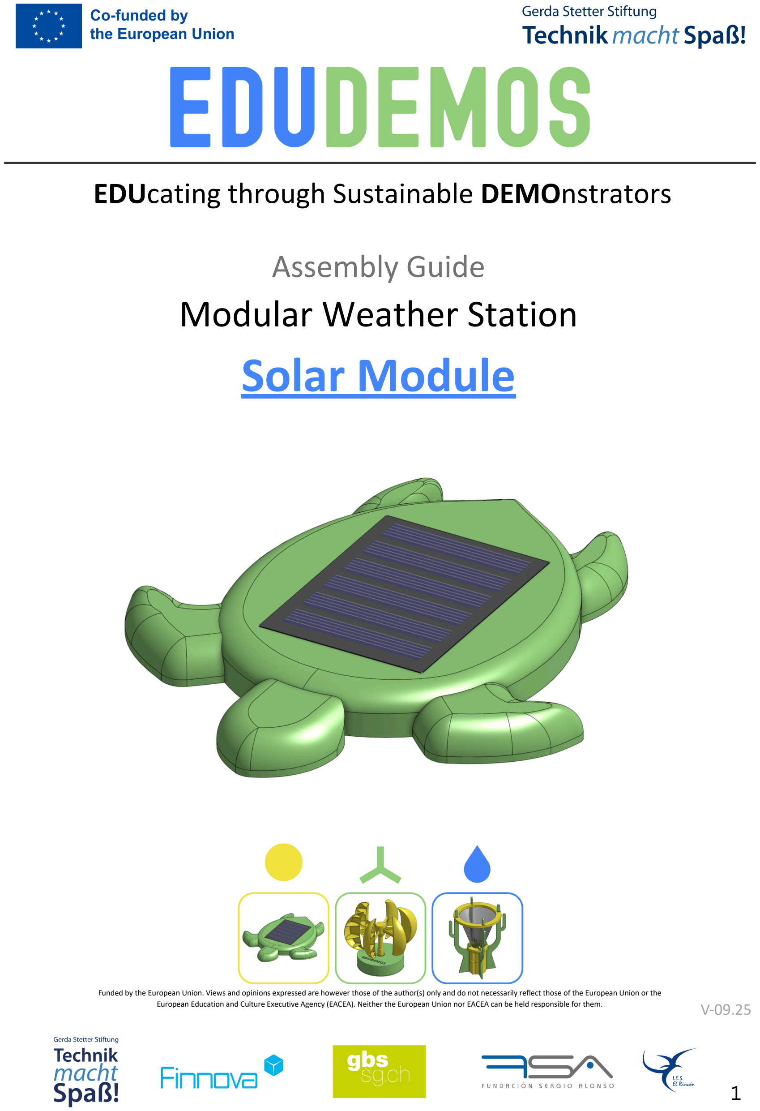
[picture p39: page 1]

Funded by the European Union. Views and opinions expressed are however those of the author(s) only and do not necessarily reflect those of the European Union or the European Education and Culture Executive Agency (EACEA). Neither the European Union nor EACEA can be held responsible for them.

# Modular Weather Station

# Solar Module

V-09.25

## 1.Materials 2.Step by step Instructions a.Printing the parts b.Building the Sun Module 3.Attachments a.Licensing & Disclaimer 4.Contact Information

# Content

# Materials

## 1x Solar panel (Includes wires)

# Electrical Components

# 3D-Printer

## 3D-Filament for the Turtle (ca. 45g)

# Optional

## 2x Jumper M-M wire to extend the included wires from the solar panel 2x Lusterterminals to connect those extension wires to the wires from the solar panel

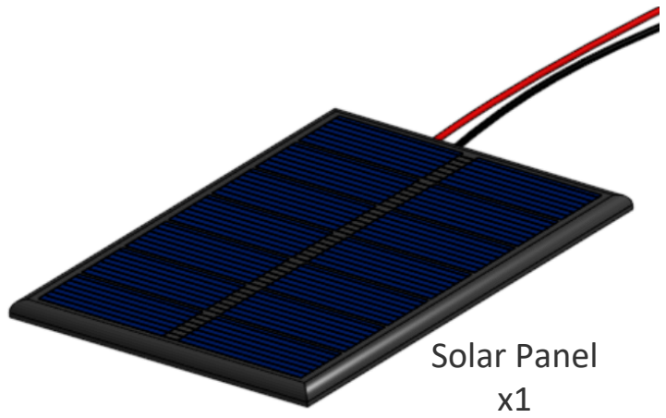
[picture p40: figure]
Solar Panel x1

### Total 2 elements

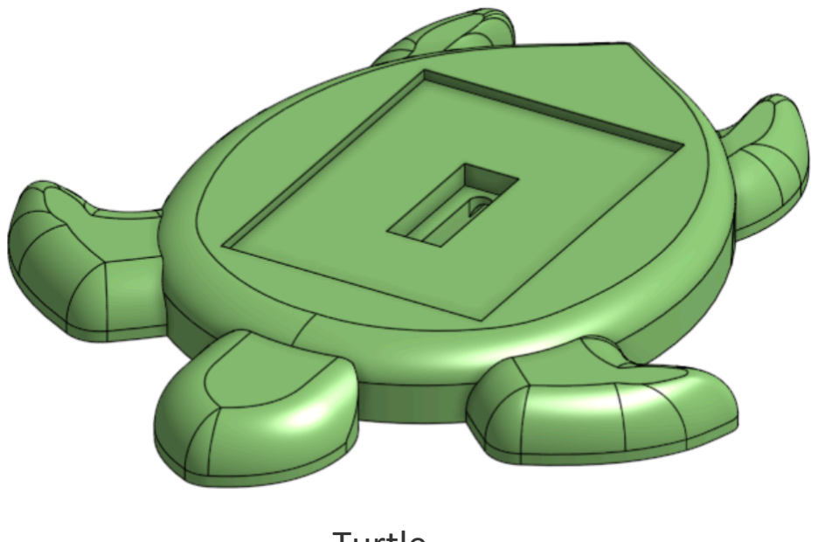
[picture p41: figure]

Turtle
x1

# Materials

# Step by step Instructions

## a. Print the Turtle on any 3D-Printer

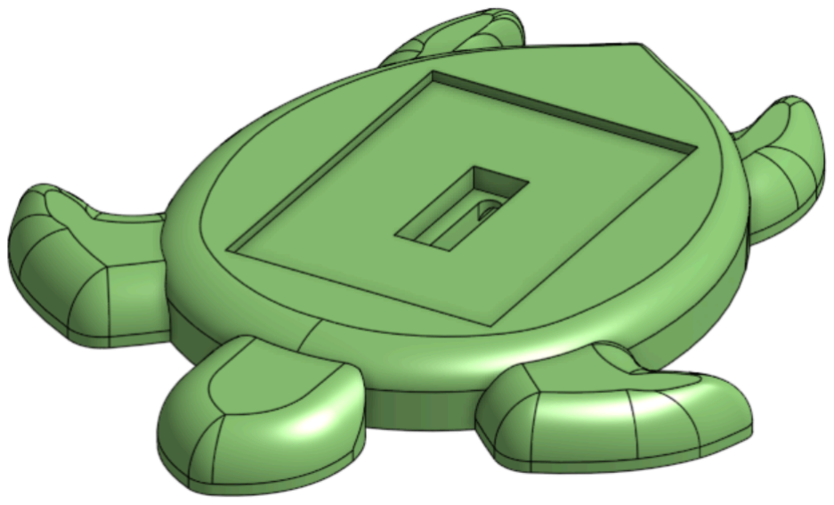
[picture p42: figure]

The STL-printfiles
are available on
the EduDemoS
webpage.

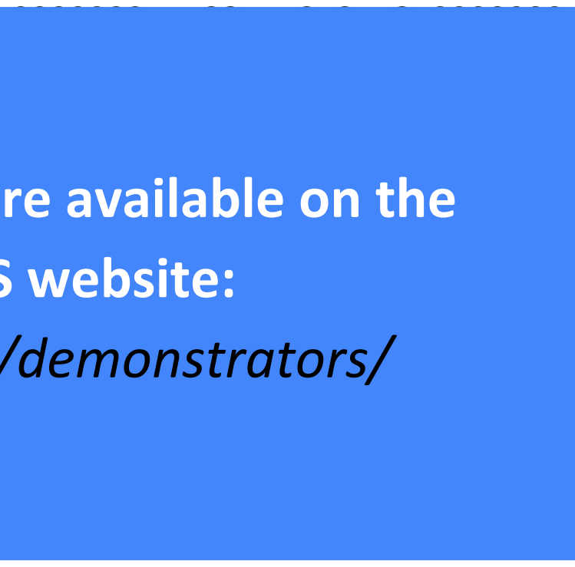
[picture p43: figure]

The STL print files are available on the EduDemoS website:
edudemos.eu/en/demonstrators/

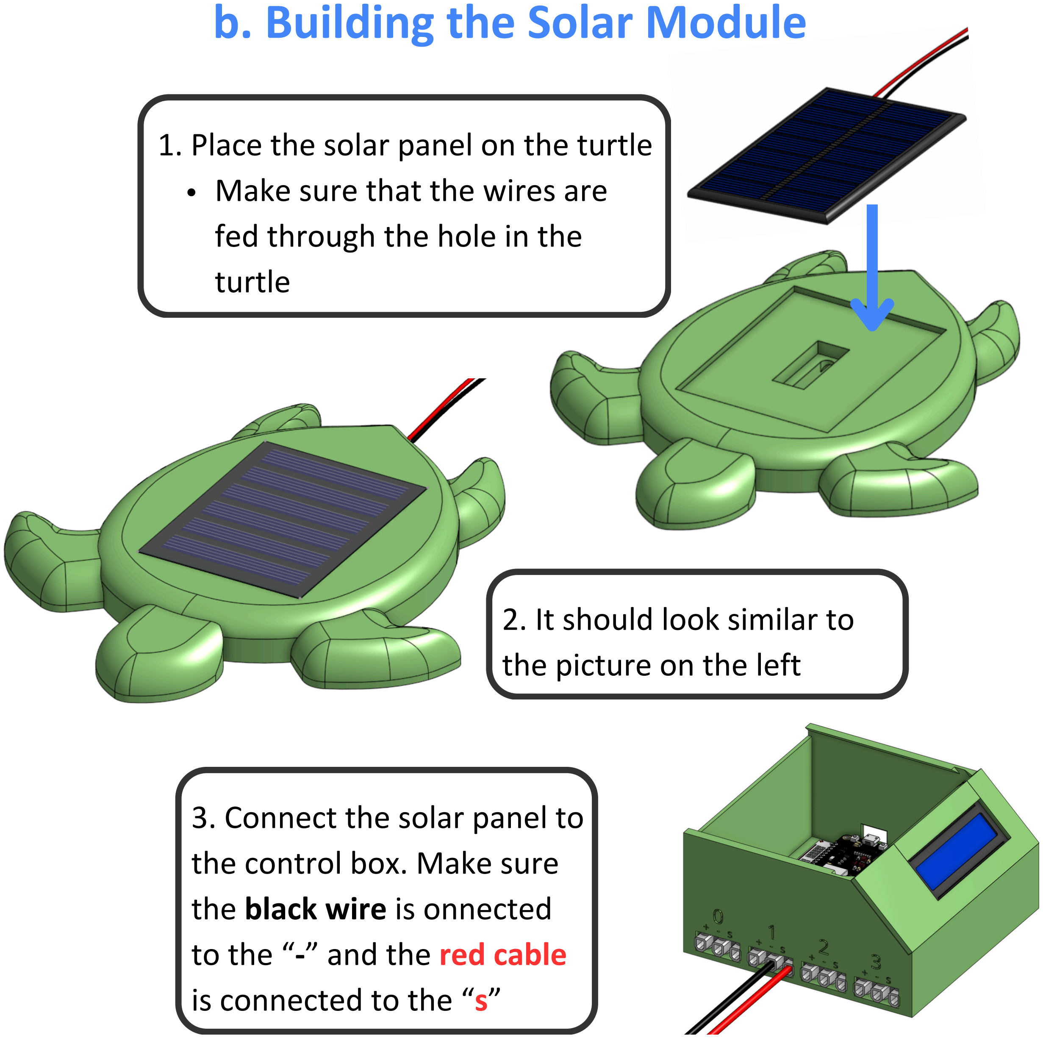
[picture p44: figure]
2. It should look similar to the picture on the left; 1. Place the solar panel on the turtle Make sure that the wires are fed through the hole in the turtle; b. Building the Solar Module; 3. Connect the solar panel to the control box. Make sure the black wire is onnected to the “; ” and the red cable is connected to the “s”

What other modules can you imagine?
Personalize your own demonstrator, and share your ideas and feedback with us at
edudemos@technikmachtspass.org

# Attachments

EduDemoS Modular Weather Station © 2025 by Gerda Stetter Stiftung – Technik macht Spaß! is licensed under Creative Commons Attribution-NonCommercial-ShareAlike 4.0 International. To view a copy of this license, visit https://creativecommons.org/licenses/by-nc-sa/4.0/

All Circuits were created with Fritzing. (https://fritzing.org/)
Some images are based on modules from GrabCAD Library. (https://grabcad.com/library)

## Licensing

## Disclaimer

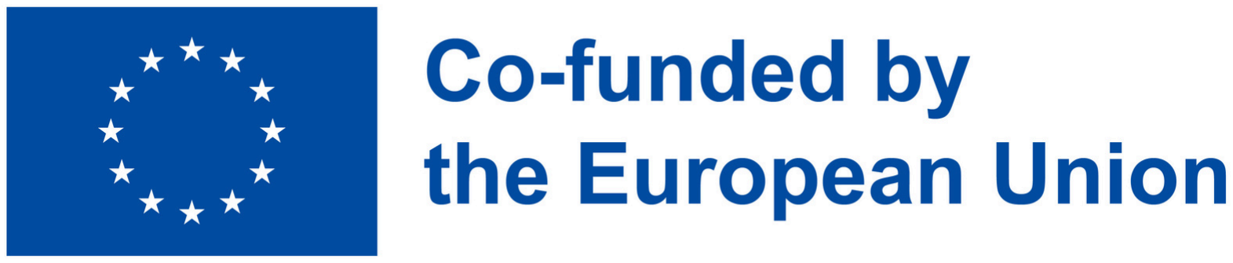
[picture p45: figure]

Funded by the European Union. Views and opinions expressed are however those of the author(s) only and do not necessarily reflect those of the European Union or the European Education and Culture Executive Agency (EACEA). Neither the European Union nor EACEA can be held responsible for them.

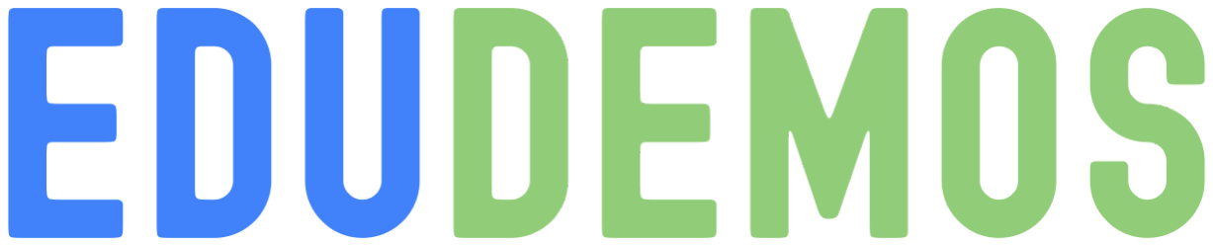
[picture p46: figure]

# Get In Touch With Us

## edudemos@technikmachtspass.org

## EDUcating through Sustainable DEMOnstrators

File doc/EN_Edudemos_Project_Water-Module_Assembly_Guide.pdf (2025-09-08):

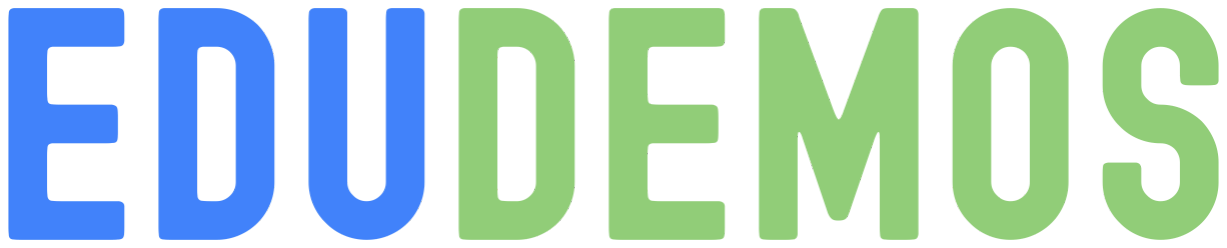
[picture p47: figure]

## EDUcating through Sustainable DEMOnstrators

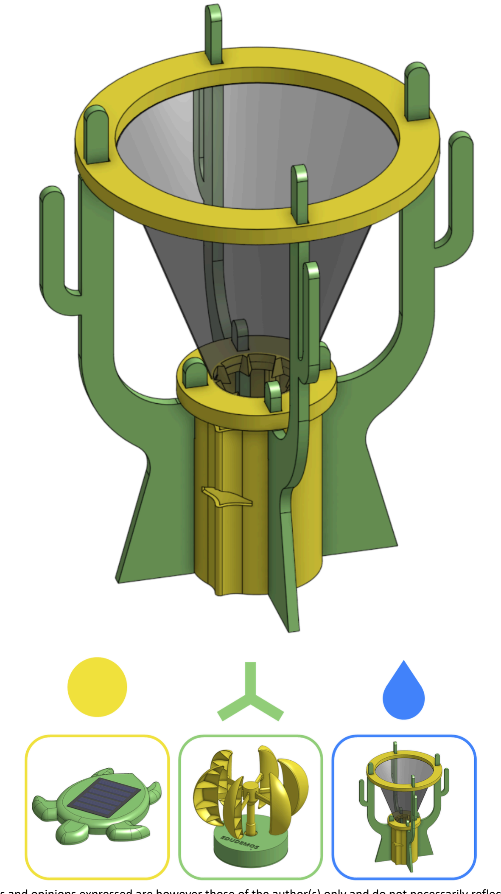
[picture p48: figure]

Funded by the European Union. Views and opinions expressed are however those of the author(s) only and do not necessarily reflect those of the European Union or the European Education and Culture Executive Agency (EACEA). Neither the European Union nor EACEA can be held responsible for them.

## Assembly Guide

# Modular Weather Station

# Water Collector Module

V-09.25

## 1.Materials 2.Step by Step Instructions a.Printing the parts b.Building the Water Collector 3.Attachments a.Optional metal-mesh cone b.Licensing & Disclaimer 4.Contact Information

# Content

# Materials

## 1x Water Level Sensor (Arduino) 3x Jumper Wire F-M

# Electrical Components

# 3D-Printer

## 4x Cactus 1x Collector Cup 1x Lower Ring 1x Upper Ring 1x Cone

# Optional

## Metal mesh cone, 30cm*20cm (Instead of the printed cone)

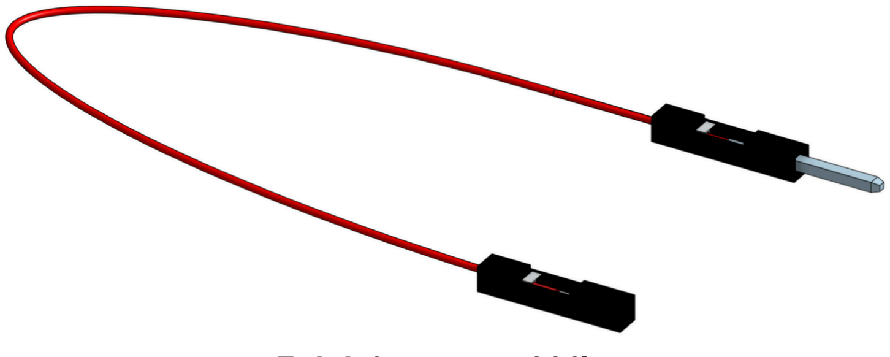
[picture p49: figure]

### Total 2 elements

# Materials

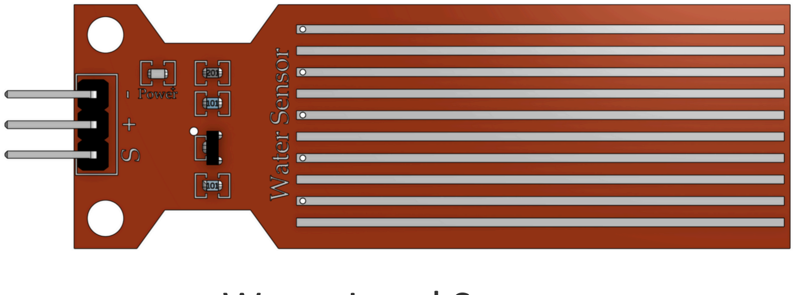
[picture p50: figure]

Water Level Sensor
x1

F-M Jumper Wire
x3

## Electronics

# Materials

## 3D Printed Parts

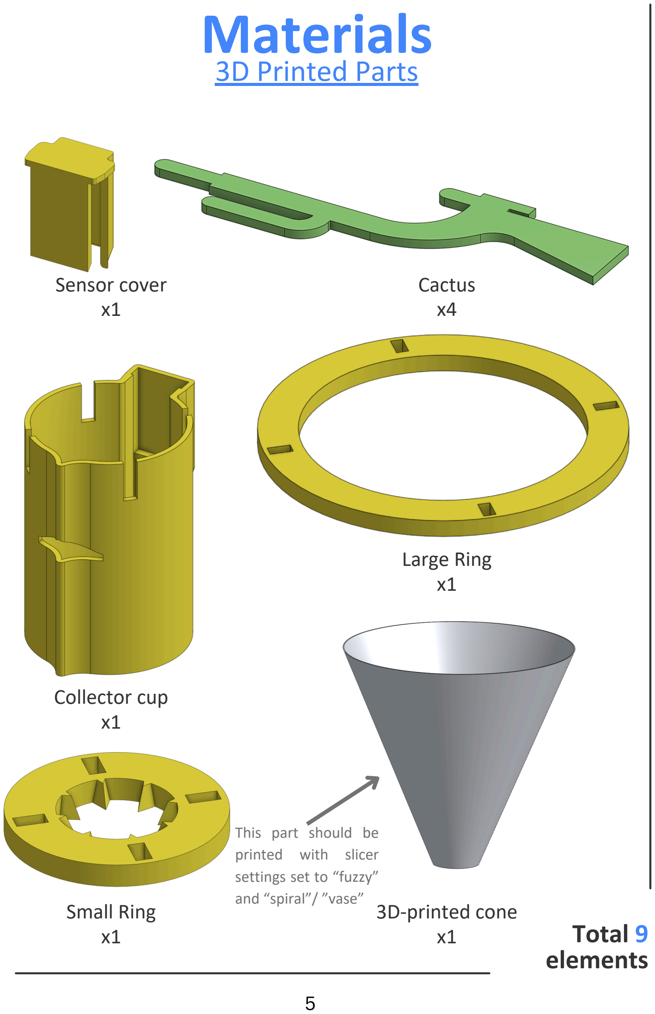
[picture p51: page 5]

### Total 9 elements

Sensor cover
x1

Cactus
x4

Collector cup
x1

Small Ring
x1

Large Ring
x1

3D-printed cone
x1

This part should be
printed with slicer
settings set to “fuzzy”
and “spiral”/ ”vase”

# Step By Step Instructions

## a. Print the parts of the Cactus on any 3D-Printer

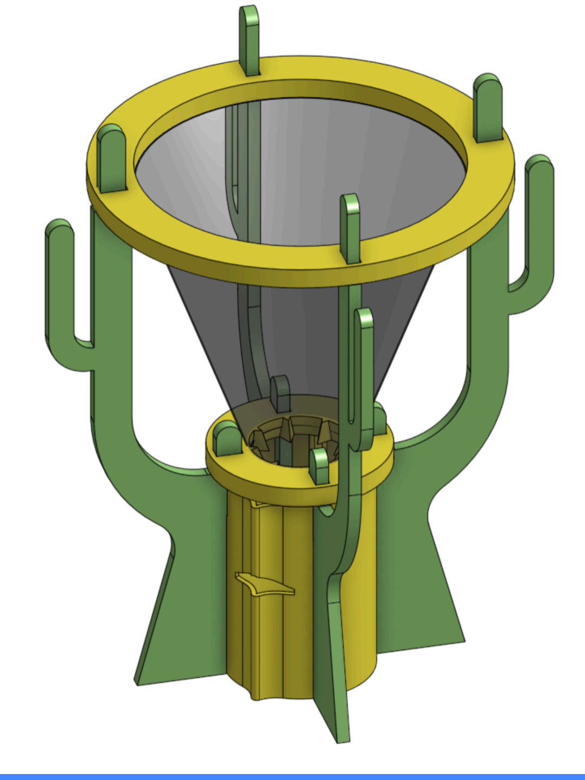
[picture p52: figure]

The STL print files are available on the EduDemoS website:
edudemos.eu/en/demonstrators/

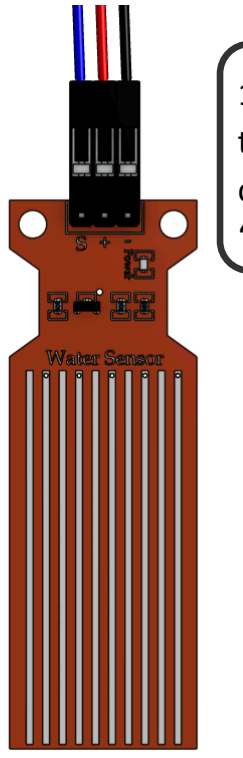
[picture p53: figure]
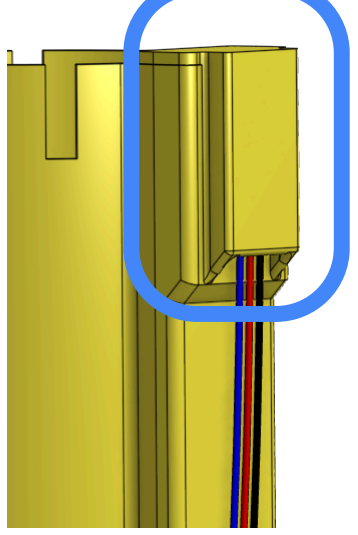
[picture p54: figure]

3. Now enclose the cables and the sensor with the sensor cover
1. Connect 3 F-M Jumper wires to the water level sensor and to the controlbox. Make sure to connect “+” to “+”

,

“

” to “

” and “s” to “s”

## b. Building the Water Collector


2. Slide the sensor into its holder on the water collector



4. Slide the cacti into the corresponding cutouts in
the collector cup


5. Finally:
Slide the smaller ring into place
The cone is supposed to sit loosly on the “teeth” of the small ring


Make sure that the cone slides into the slot of the top ring


Which other modules can you imagine?

Personalize your own demonstrator, and share your ideas and feedback with us at
edudemos@technikmachtspass.org
6. Finally it looks like
this.

# Attachments

# a. Optional metal-

mesh cone

With this template you can make an
optional cutout from a metal mesh
(or similar) and make your own cone
instead of printing one.

Roll it up and connect the ends using
wire, glue or a stapler.

Important: Make sure to print this
page borderless!

Why do this?
A metal mesh offers
more surface area for
water to deposit and is
better at absorbing heat.
This will increase the
amount of water
collected by this module.

Use gloves when
handling metal mesh. It
can have sharp edges!

## Licensing

EduDemoS Modular Weather Station © 2025 by Gerda Stetter Stiftung – Technik macht Spaß! is licensed under Creative Commons Attribution-NonCommercial-ShareAlike 4.0 International. To view a copy of this license, visit https://creativecommons.org/licenses/by-nc-sa/4.0/

All Circuits were created with Fritzing. (https://fritzing.org/)
Some images are based on modules from GrabCAD Library. (https://grabcad.com/library)

## Disclaimer


Funded by the European Union. Views and opinions expressed are however those of the author(s) only and do not necessarily reflect those of the European Union or the European Education and Culture Executive Agency (EACEA). Neither the European Union nor EACEA can be held responsible for them.


# Get In Touch With Us

## edudemos@technikmachtspass.org

## EDUcating through Sustainable DEMOnstrators

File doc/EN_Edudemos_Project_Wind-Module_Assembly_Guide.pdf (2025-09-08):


## EDUcating through Sustainable DEMOnstrators


Funded by the European Union. Views and opinions expressed are however those of the author(s) only and do not necessarily reflect those of the European Union or the European Education and Culture Executive Agency (EACEA). Neither the European Union nor EACEA can be held responsible for them.

## Assembly Guide

# Modular Weather Station

# Wind Turbine Module

V-09.25

## 1.Materials 2.Step by step instructions a.Printing the parts b.Building the Wind Module 3.Attachments a.Licensing & Disclaimer 4.Contact information

# Content

# Materials

## 2x Wires, length: at least 20cm 1x DC Motor 1x Bearing 608zz (8mm x 22mm x 7mm)

# Electrical Components

# 3D-Printer

## 3D-Filament for the Windturbine (ca. 185g)

# Materials


### Total 15 elements

Lid
x1


Shovel
x6


Large gear
x1


Base
x1

Small gear
x1

608zz Bearing
x1

DC Motor
x1

Wire (>20cm)
x2

Shaft
x1
This part should be printed with higher wall count

# Step By step Instructions

## a. Print the parts of the Wind Module on any 3D-Printer


The STL print files are available on the EduDemoS website:
edudemos.eu/en/demonstrators/

## b. Building the Wind Module


1. Each wire needs to be
connected to the DC motor at its
solder pads.
The easiest way is to solder
the wires directly onto the
pads.
If you don’t have a soldering
iron, you can try threading
the wire ends through the
holes or loops in the pads and
twisting them together.

2. Stick the small gear onto the
DC-Motor Axis and make sure it
fits very tight.
If the gear is to loose try to
fasten it with a drop of glue.

3. Now place the DC-
Motor into its place on
the 3D printed floor.
Make sure to guide
the wire through
the little tunnel as
you can see on the
close up picture on
the right.


4. One after the other
slide the peaces into
their place.
First: The Bearing
Second: The large
gear
Third: The lid

6. To connect the shovel with the shaft,
slightly tilt the shovel upwards, push the end
into the opening and once it is in, push it
carefully down until you feel it click into
place.


7. Repeat the previous
step six times until all
shovels are connected
8. Last but not least slide the shaft with the shovels into its place on the base.
9. Make sure the turbine can rotate smoothly and has good contact with the motor gear.


What other modules can you imagine?

Personalize your own demonstrator, and share your ideas and feedback with us at
edudemos@technikmachtspass.org
10. Finaly you can connect the Wind Module. Connect the
wires to the “

” and the “s”
terminals.
11. If you're having trouble seeing any voltage generated, check the wiring. The two wires should be connected to the '

'
and 's' slots, but you may need to switch between the '

' and 's'
slots to ensure proper
connection.

# Attachments

## Licensing

## Disclaimer


Funded by the European Union. Views and opinions expressed are however those of the author(s) only and do not necessarily reflect those of the European Union or the European Education and Culture Executive Agency (EACEA). Neither the European Union nor EACEA can be held responsible for them.

EduDemoS Modular Weather Station © 2025 by Gerda Stetter Stiftung – Technik macht Spaß! is licensed under Creative Commons Attribution-NonCommercial-ShareAlike 4.0 International. To view a copy of this license, visit https://creativecommons.org/licenses/by-nc-sa/4.0/

All Circuits were created with Fritzing. (https://fritzing.org/)
Some images are based on modules from GrabCAD Library. (https://grabcad.com/library)


# Get In Touch With Us

## edudemos@technikmachtspass.org

## EDUcating through Sustainable DEMOnstrators

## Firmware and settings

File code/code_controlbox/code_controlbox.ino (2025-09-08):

/*
* This file is part of the EduDemoS Modular Weatherstation which is
* co-funded by the European Union.
* Copyright (C) 2025  Gerda Stetter Stiftung - Technik macht Spaß!
*
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
* You should have received a copy of the GNU General Public License
* along with this program.  If not, see <http://www.gnu.org/licenses/>.
*/

// Import the needed libaries from the libaries folder on your PC.
#include <Wire.h>                                                     // Include the libary for communication with I2C devices like the PCF8591 and the LCD.
#include <LiquidCrystal_I2C.h>                                        // Include the libary for controlling the LCD with I2C.

LiquidCrystal_I2C lcd(0x27,16,2);                                     // Set the LCD address (0x27) and the number of columns (16) and rows (2).

// Define PCF8591     
#define PCF8591_ADRESS 0x48                                           // I2C-Adress of the PCF8591 (Standard: 0x48)
#define PCF8591_V_REF 5.0                                             // Reference voltage for the PCF8591 (5V is the voltage provided by USB)
#define PCF8591_RESOLUTION 255.0                                      // Resolution of the PCF8591 (Standard: 255 - Depends on the specific PCF8591 used)

// Settings for different modules
// These define how to handle specific sensors like wind, water level, or power usage.

// The calculation to transform the digital value given by the modules into the physical value depends on 
// the sensor so we use the formula physicalValue=(digitalValue*specificSlope)+specificOffset.
// In the following lines we define the sensor specific slopes and offsets.

// Voltage divider configuration for the sun and wind modules
#define VOLTAGE_DIVIDER_SLOPE 2
#define VOLTAGE_DIVIDER_OFFSET 0
#define VOLTAGE_DIVIDER_UPDATE_RATE 2                                 // How often the sensor is read (recommended: five times per second) If you change this value, errors might occur!

// Configuration for the water module     
#define WATER_LEVEL_SENSOR_V_REF 3.3                                  // Reference voltage for the Water-Level Sensor (3.3V is the voltage provided by the GPIO pins.)
#define WATER_LEVEL_SENSOR_SLOPE (WATER_LEVEL_SENSOR_V_REF / 4)     
#define WATER_LEVEL_SENSOR_OFFSET 0     
#define WATER_LEVEL_SENSOR_UPDATE_RATE 60                             // [1/10 s] -> once in six seconds (To prevent the waterlevel sensor from rusting we do not read the data as often as with the other sensors.)

// Configuration for the current sensor used to measure the power consumption of the whole demonstrator
#define ACS712_SENSITIVITY 0.185                                      // This value depends on the model used. We recommend the 5 Ampere version which has a sensitivity of 0.185. It is the most accurate ACS712 model.
#define ACS712_V_REF 5.0                                              // Reference voltage for the ACS712 (5V is the voltage provided by USB.)
#define ACS712_SLOPE (1/ACS712_SENSITIVITY)     
#define ACS712_OFFSET (-ACS712_V_REF/(2*ACS712_SENSITIVITY))      
#define ACS712_UPDATE_RATE 2      

// Define visualization     

// LCD      
#define LCD_FIELD_LENGTH 8                                            // [16/2] -> Space for each value on the screen 
#define LCD_UPDATE_RATE 2                                             // [1/10 s] -> Five times per second
// Serial Communication (via USB to your Computer)      
#define SERIAL_UPDATE_RATE 20                                         // [1/10 s] -> Once every two seconds


// Define the struct (a digital container, in this case for sensor data)
// This makes it easy to manage and organize settings for each sensor.
// After defining the struct this code only uses the number of the analog channel. 
// You can see the number on the PCF8591 and written over the 4 Lusterterminals on the controlbox. 
// For programming we count up from zero so instead of 1-2-3-4 our channels are named 0-1-2-3.
// For each channel the data for the connected module/sensor is put in.

// Channel 0
#define ZERO_NEEDS_GPIO_POWER false 
#define ZERO_GPIO_POWER_PIN 15  
#define ZERO_SLOPE VOLTAGE_DIVIDER_SLOPE  
#define ZERO_OFFSET VOLTAGE_DIVIDER_OFFSET  
#define ZERO_UPDATE_RATE VOLTAGE_DIVIDER_UPDATE_RATE  
// Channel 1
#define ONE_UPDATE_RATE VOLTAGE_DIVIDER_UPDATE_RATE 
#define ONE_NEEDS_GPIO_POWER false  
#define ONE_GPIO_POWER_PIN 13 
#define ONE_SLOPE VOLTAGE_DIVIDER_SLOPE 
#define ONE_OFFSET VOLTAGE_DIVIDER_OFFSET 
// Channel 2
#define TWO_NEEDS_GPIO_POWER true                                     // Needs to be turned on to take measurements.
#define TWO_GPIO_POWER_PIN 12
#define TWO_SLOPE WATER_LEVEL_SENSOR_SLOPE
#define TWO_OFFSET WATER_LEVEL_SENSOR_OFFSET
#define TWO_UPDATE_RATE WATER_LEVEL_SENSOR_UPDATE_RATE
// Channel 3
#define THREE_NEEDS_GPIO_POWER false
#define THREE_GPIO_POWER_PIN 14
#define THREE_SLOPE ACS712_SLOPE
#define THREE_OFFSET ACS712_OFFSET
#define THREE_UPDATE_RATE ACS712_UPDATE_RATE

// ---
// This is the end of the settings part. For most changes (like module swaps) you won't need to change anything below because you can just adjust the settings above.
// ---

// Create the struct
typedef struct{
  bool needsPower;                                                    // Does the sensor need to be turned on?
  int powerPin;                                                       // Which pin controls the sensor's power?
  float slope;                                                        // Conversion factor to turn digital sensor values into physical numbers
  float offset;                                                       // Offset parameter for digital-to-physical conversion
  long updateRate;                                                    // How often a measurement is made (in tenths of a second)
  float lastMeasurement;                                              // The most recent reading from this sensor
} ch;     

ch channel[4] = {0};                                                  // Create 4 channels from the struct to connect up to 4 sensors/modules.


void setup() {      
  Serial.begin(9600);                                                 // Start serial communication with the connected computer.
  Wire.begin();                                                       // Start the I²C connection.
  lcd.begin();                                                        // Connect to the LCD.
  Wire.onReceive(receiveEvent);     
// Put the earlier defined sensor-data into the struct        
// Channel 0:     
  channel[0].needsPower = ZERO_NEEDS_GPIO_POWER;                      
  channel[0].powerPin = ZERO_GPIO_POWER_PIN;                          // (D8)
  channel[0].slope = ZERO_SLOPE;                                      
  channel[0].offset = ZERO_OFFSET;                                    
  channel[0].updateRate = ZERO_UPDATE_RATE;                           
// Channel 1:     
  channel[1].needsPower = ONE_NEEDS_GPIO_POWER;                       
  channel[1].powerPin = ONE_GPIO_POWER_PIN;                           // (D7)
  channel[1].slope = ONE_SLOPE;                                       
  channel[1].offset = ONE_OFFSET;                                     
  channel[1].updateRate = ONE_UPDATE_RATE;                            
  // Channel 2:     
  channel[2].needsPower = TWO_NEEDS_GPIO_POWER;                     
  channel[2].powerPin = TWO_GPIO_POWER_PIN;                           // (D6)  
  channel[2].slope = TWO_SLOPE;                                     
  channel[2].offset = TWO_OFFSET;                                   
  channel[2].updateRate = TWO_UPDATE_RATE;                          
  // Channel 3:     
  channel[3].needsPower = THREE_NEEDS_GPIO_POWER;                   
  channel[3].powerPin = THREE_GPIO_POWER_PIN;                         // (D5)  
  channel[3].slope = THREE_SLOPE;                                 
  channel[3].offset = THREE_OFFSET;                                 
  channel[3].updateRate = THREE_UPDATE_RATE;                        

  for(int i = 0; i < 4; i++){     
    pinMode(channel[i].powerPin, OUTPUT);                             // Enable the power connection to power sensors/modules through GPIO pins if needed.
    digitalWrite(channel[i].powerPin, LOW);                           // Turn off the power on the pins.
  }     

  delay(1000);                                                        // Wait for the serial connection to your computer to be established.
  for(int i = 0; i < 4; i++){                                         // Send the settings for each channel to your computer.
    Serial.println(channel[i].slope);
    Serial.println(channel[i].offset);
    Serial.println(channel[i].updateRate);
    Serial.println(channel[i].needsPower);
    Serial.println();
  }  
  Serial.println("Setup okay");
}

void loop() {
  long mil = millis();                                                // Get the duration the program already ran in milliseconds.
  for(int i = 0; i < 4; i++){                                         // Loop through all channels.
    if((mil % (100 * channel[i].updateRate)) == 0){                   // Check the channel if the duration, that the program has run, is divisible by the set update rate.
      channel[i].lastMeasurement = measureAndConvert(i);      
    }     
    if ((mil % (100*LCD_UPDATE_RATE)) == 0){                          // Update the LCD if the duration, that the program has run, is divisible by the set update rate.
      updateLCD(i, output(i));      
    }     
    if ((mil % (100*SERIAL_UPDATE_RATE)) == 0){                       // Send the recent measurements to your computer if the duration, that the program has run, is divisible by the set update rate.
      updateSerial(output(i));      
    }     
  }     
}     

void receiveEvent(int howMany) {      
   while (0 <Wire.available()) {      
    char c = Wire.read();                                             // Receive the byte as a character.
    Serial.print(c);                                                  // Print the character.
  }                                       
 Serial.println();                                                    // Go to a new line.
}

// Function for reading the Channel with the given ID and converting it into the current analog(voltage) input.
float input(int analogChannelID) {
  if(channel[analogChannelID].needsPower){                            // Power the sensors that need powering through GPIO pins.
    digitalWrite(channel[analogChannelID].powerPin, HIGH);      
    delay(10);      
    };                                                                
  Wire.beginTransmission(PCF8591_ADRESS);     
  Wire.write(0x40 | analogChannelID);       
  Wire.endTransmission();     
  Wire.requestFrom(PCF8591_ADRESS, 2);      
  if (Wire.available() >= 2) {      
    Wire.read();                                                      // Discard the first value.
    float reading = (Wire.read()*(PCF8591_V_REF/PCF8591_RESOLUTION)); // Convert the reading into the analog(voltage) input.
    if(channel[analogChannelID].needsPower){                          // Stop powering the sensors that need powering through GPIO pins.
      digitalWrite(channel[analogChannelID].powerPin, LOW);
      };                                                        
    return (reading);                                                 // Return the calculated analog(voltage) input.
  }
  return 0;                                                           // In case of error. This line is only reached if something went wrong.
}


// Funtion for converting the input on the given channel into the actual measurement data of the connected sensor using the formula mentioned in the beginning.
float measureAndConvert(int analogChannelID){
  return ((input(analogChannelID) * channel[analogChannelID].slope) + channel[analogChannelID].offset);
}

// Put the calculated value with up to 5 decial places, with the channel in front, into a string (text variable) that has the length of the LCD field (defined earlier).
String output(int analogChannelID){
  String str = String(analogChannelID) + ":" + String(channel[analogChannelID].lastMeasurement, 5);
  while(str.length() <= LCD_FIELD_LENGTH){
    str += ' ';
  }
  if(str.length() > LCD_FIELD_LENGTH){
    str = str.substring(0, (LCD_FIELD_LENGTH - 1));
  } 
  return str;
}

// Function to update the specific field of the LCD for each channel.
void updateLCD(int analogChannelID, String output){
  int row;
  int colStart = 0;
  switch(analogChannelID){
    case 0:
      row = 0;
      colStart = 0;
      break;
    case 1:
      row = 0;
      colStart += LCD_FIELD_LENGTH;
      break;
    case 2:
      row = 1;
      colStart = 0;
      break;
    case 3:
      row = 1;
      colStart += LCD_FIELD_LENGTH;
      break;
    default:
      break;
  }
  lcd.setCursor(colStart, row);
  lcd.print(output);
}

// Function to send the channel specific output to your computer.
void updateSerial(String output){
  Serial.println(output);
}

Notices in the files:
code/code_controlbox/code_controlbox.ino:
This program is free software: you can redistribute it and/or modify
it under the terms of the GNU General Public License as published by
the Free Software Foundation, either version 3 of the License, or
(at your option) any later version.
